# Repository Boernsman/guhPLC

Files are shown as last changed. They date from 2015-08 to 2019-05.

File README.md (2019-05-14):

# nymea PLC
The purpose was to design a smart home server that runns guhIO and is especially fittet to the needs of single-family house builders. It is the central switching unit that can be mounted into the electrical cabinet.

Please note: guhPLC is the abbreviation for 'guh' programmable logic controller. The smart home server has no powerline interface yet.

The layout is not yet tested - no warranty for functionality

	Copyright guh GmbH 2015-2019.

	This documentation describes Open Hardware and is licensed under the CERN OHL v. 1.2.

	You may redistribute and modify this documentation under the terms of the CERN OHL v.1.2. (http://ohwr.org/cernohl).
	
	This documentation is distributed WITHOUT ANY EXPRESS OR IMPLIED WARRANTY, INCLUDING OF MERCHANTABILITY,
	SATISFACTORY QUALITY AND FITNESS FOR A PARTICULAR PURPOSE. Please see the CERN OHL v.1.2 for applicable conditions

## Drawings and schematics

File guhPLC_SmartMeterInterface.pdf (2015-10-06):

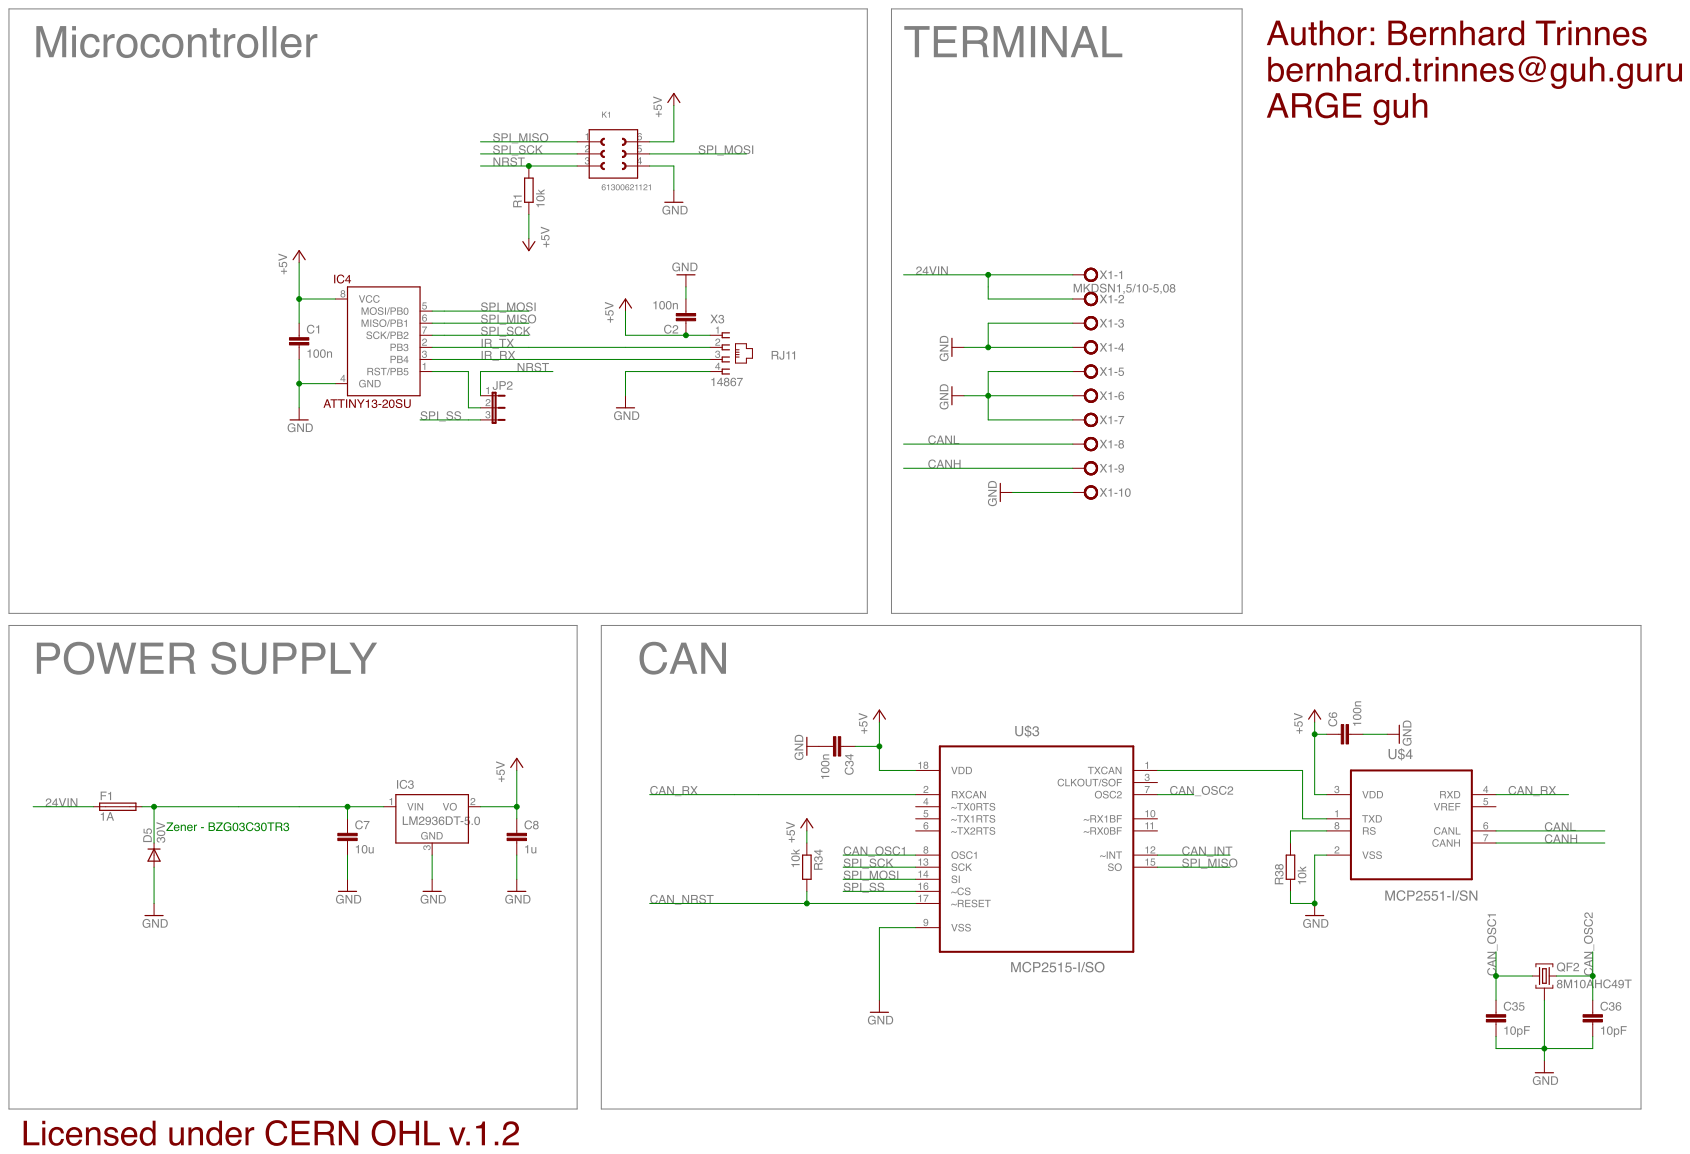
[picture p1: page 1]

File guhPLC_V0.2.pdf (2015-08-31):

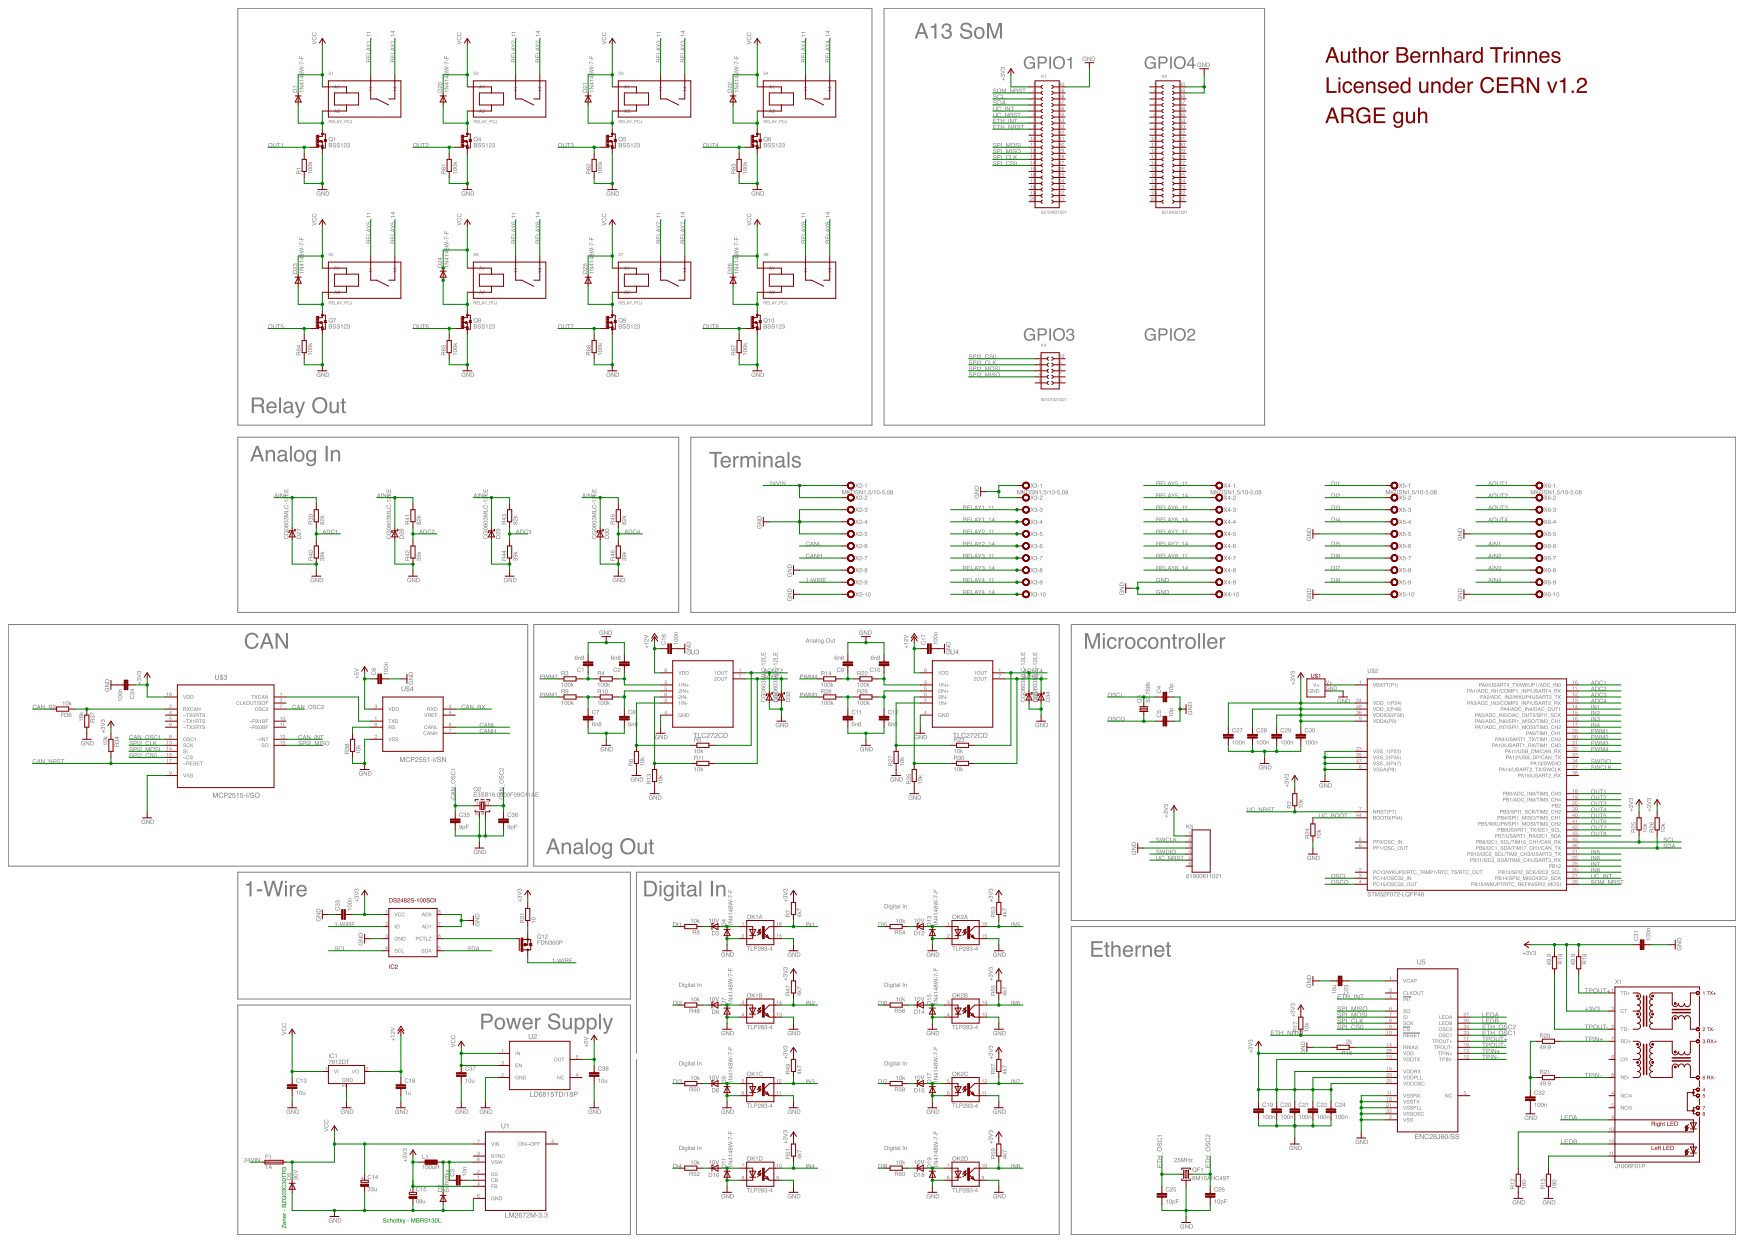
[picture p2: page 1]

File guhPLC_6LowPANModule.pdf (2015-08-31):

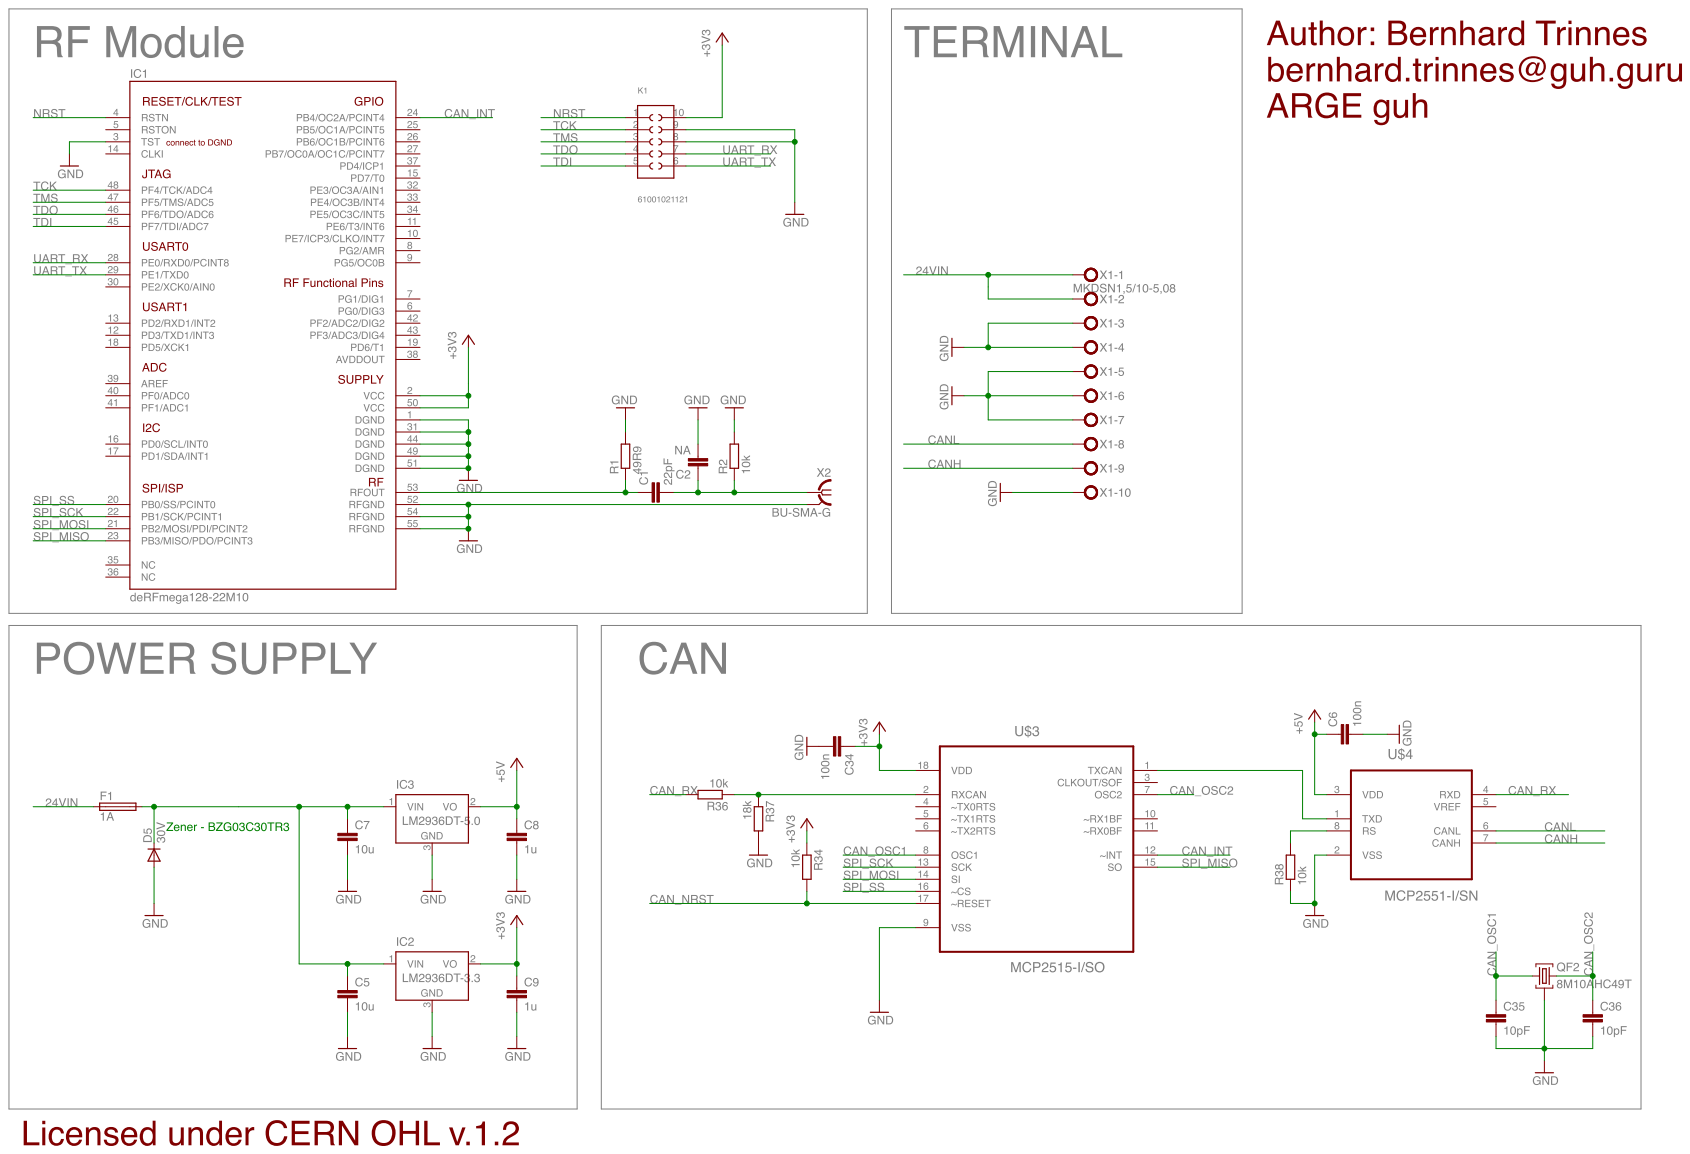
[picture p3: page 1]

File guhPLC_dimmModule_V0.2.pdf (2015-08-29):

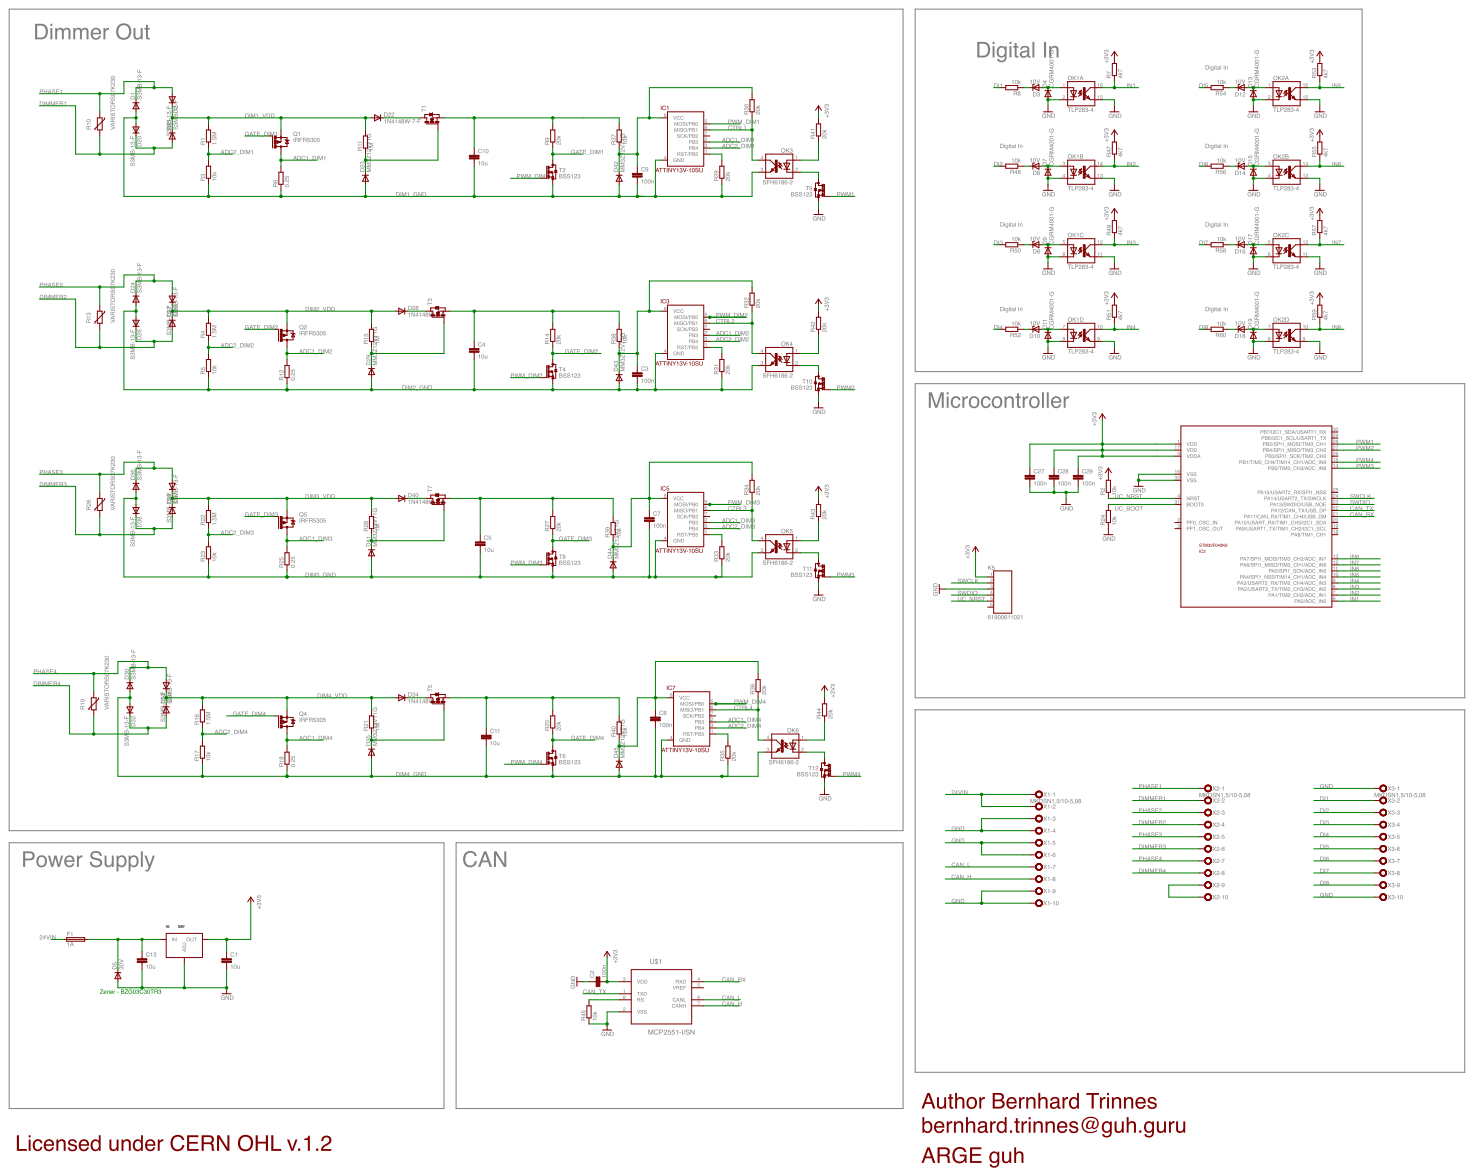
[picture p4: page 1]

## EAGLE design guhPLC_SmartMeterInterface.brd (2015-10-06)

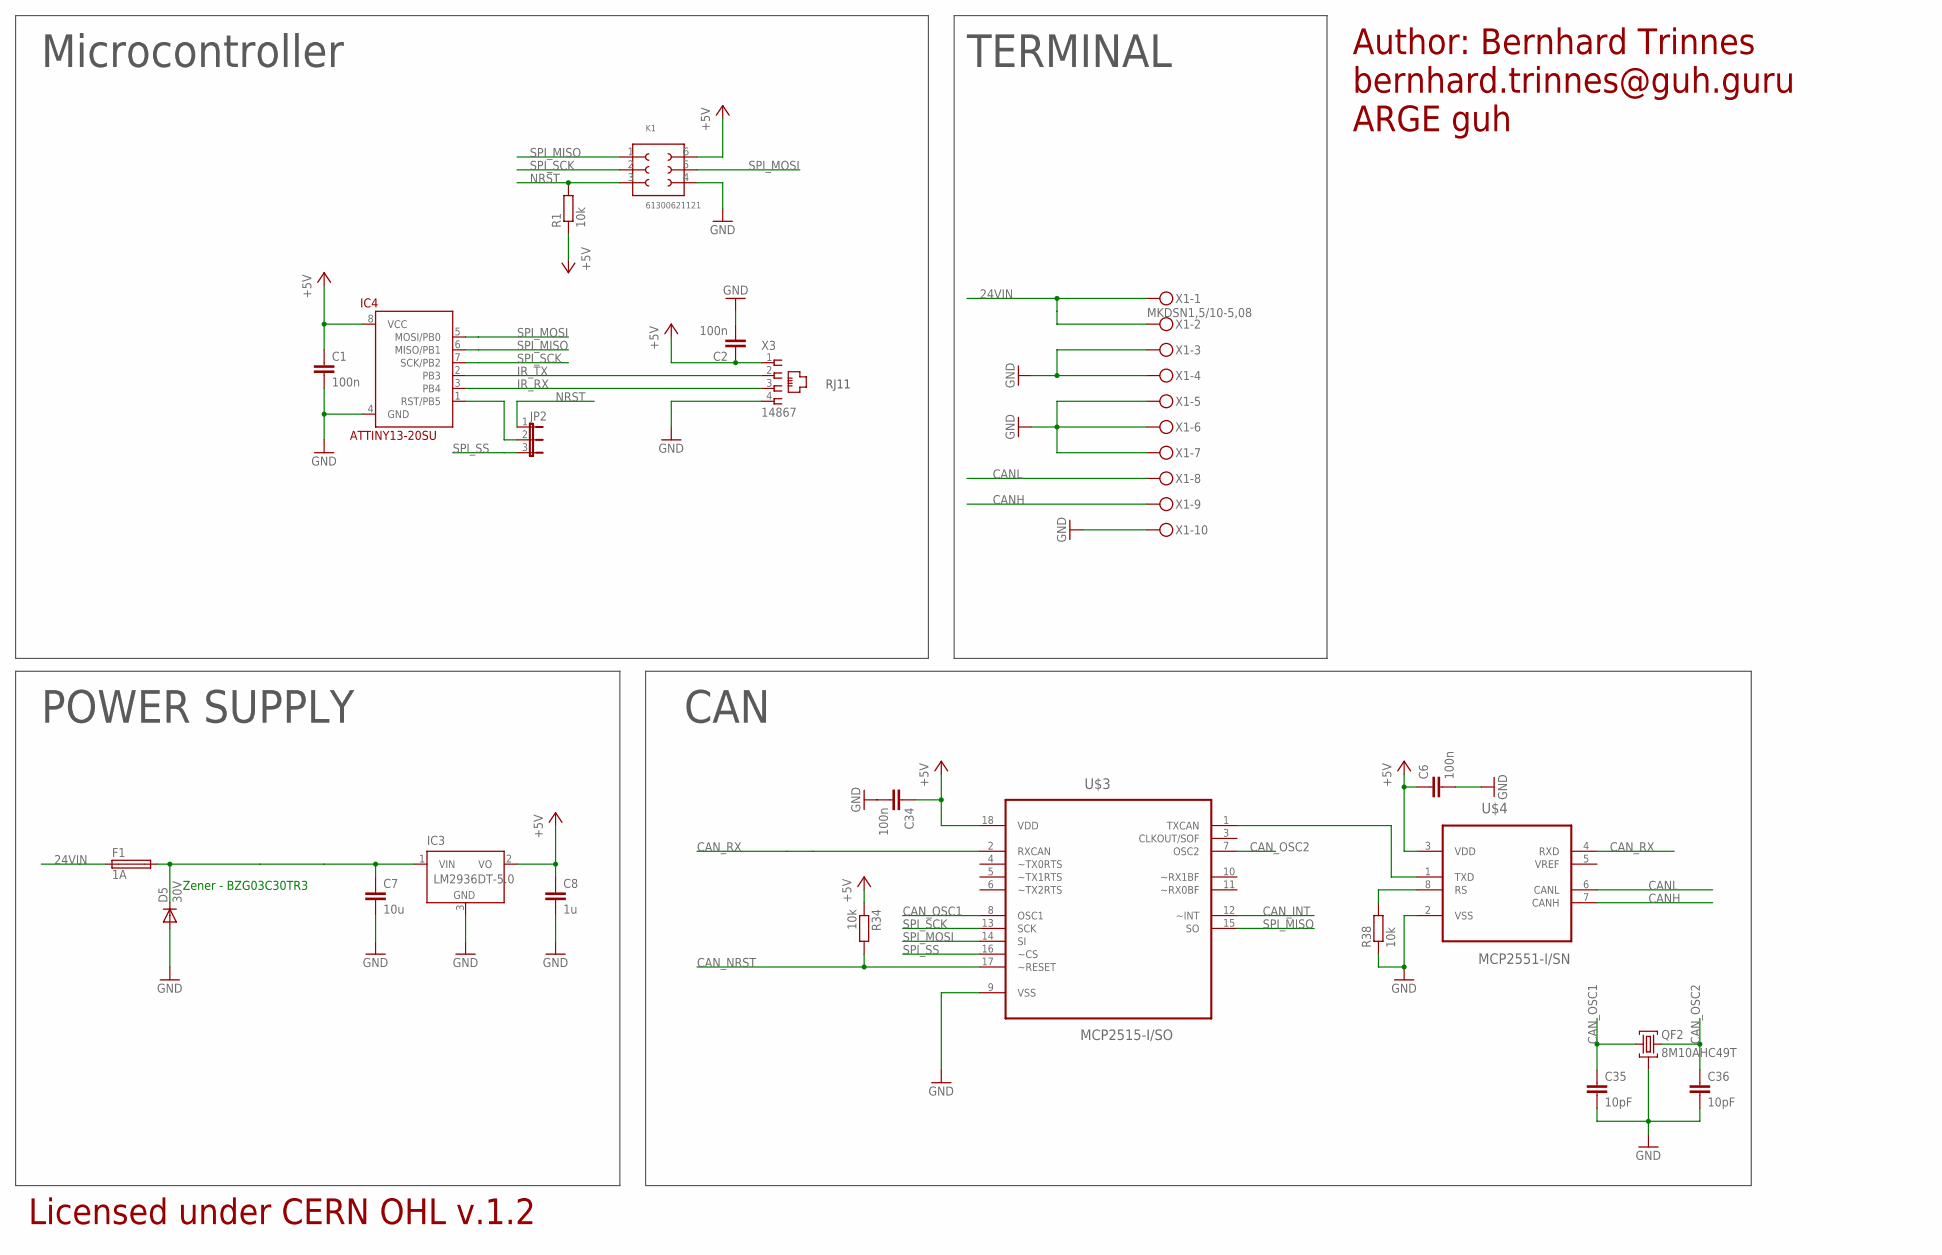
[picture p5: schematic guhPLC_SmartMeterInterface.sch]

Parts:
C1, C2, C6, C34: 100n; C0603
C7: 10u; C1206
C8: 1u; C0603
C35, C36: 10pF; C0603
D5: 30V; DO214AC
F1: 1A; LITTLEFUSE
IC3: LM2936DT-5.0; TO252
IC4: ATTINY13-20SU; SOIC8
JP2: JP2E; JP2
K1: 61300621121
QF2: 8M10AHC49T; HC49U
R1, R34, R38: 10k; R0603
U$3: MCP2515-I/SO; SOIC127P1034X264-18N
U$4: MCP2551-I/SN; SOIC127P600X175-8N
X1: MKDSN1,5/10-5,08
X3: 14867

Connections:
24VIN: F1.1, X1.1, X1.2
+5V: C1.1, C2.1, C6.1, C8.1, C34.1, IC3.2 (VO), IC4.8 (VCC), K1.6, R1.1, R34.1, U$3.18 (VDD), U$4.3 (VDD), X3.1
CANH: U$4.7 (CANH), X1.9
CANL: U$4.6 (CANL), X1.8
CAN_INT: U$3.12 (~INT)
CAN_NRST: R34.2, U$3.17 (~RESET)
CAN_OSC1: C35.1, QF2.1, U$3.8 (OSC1)
CAN_OSC2: C36.1, QF2.3, U$3.7 (OSC2)
CAN_RX: U$3.2 (RXCAN), U$4.4 (RXD)
GND: C1.2, C2.2, C6.2, C7.2, C8.2, C34.2, C35.2, C36.2, D5.A, IC3.3 (GND), IC4.4 (GND), K1.4, QF2.2, R38.1, U$3.9 (VSS), U$4.2 (VSS), X1.3, X1.4, X1.5, X1.6, X1.7, X1.10, X3.4
IR_RX: IC4.3 (PB4), X3.3
IR_TX: IC4.2 (PB3), X3.2
unnamed: IC4.1 (RST/PB5), JP2.2
unnamed: U$3.1 (TXCAN), U$4.1 (TXD)
unnamed: R38.2, U$4.8 (RS)
NRST: JP2.1, K1.3, R1.2
SPI_MISO: IC4.6 (MISO/PB1), K1.1, U$3.15 (SO)
SPI_MOSI: IC4.5 (MOSI/PB0), K1.5, U$3.14 (SI)
SPI_SCK: IC4.7 (SCK/PB2), K1.2, U$3.13 (SCK)
SPI_SS: JP2.3, U$3.16 (~CS)
VCC: C7.1, D5.C, F1.2, IC3.1 (VIN)

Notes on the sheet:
CAN
POWER SUPPLY
Microcontroller
TERMINAL
Author: Bernhard Trinnes
bernhard.trinnes@guh.guru
ARGE guh
Licensed under CERN OHL v.1.2
Zener - BZG03C30TR3
RJ11

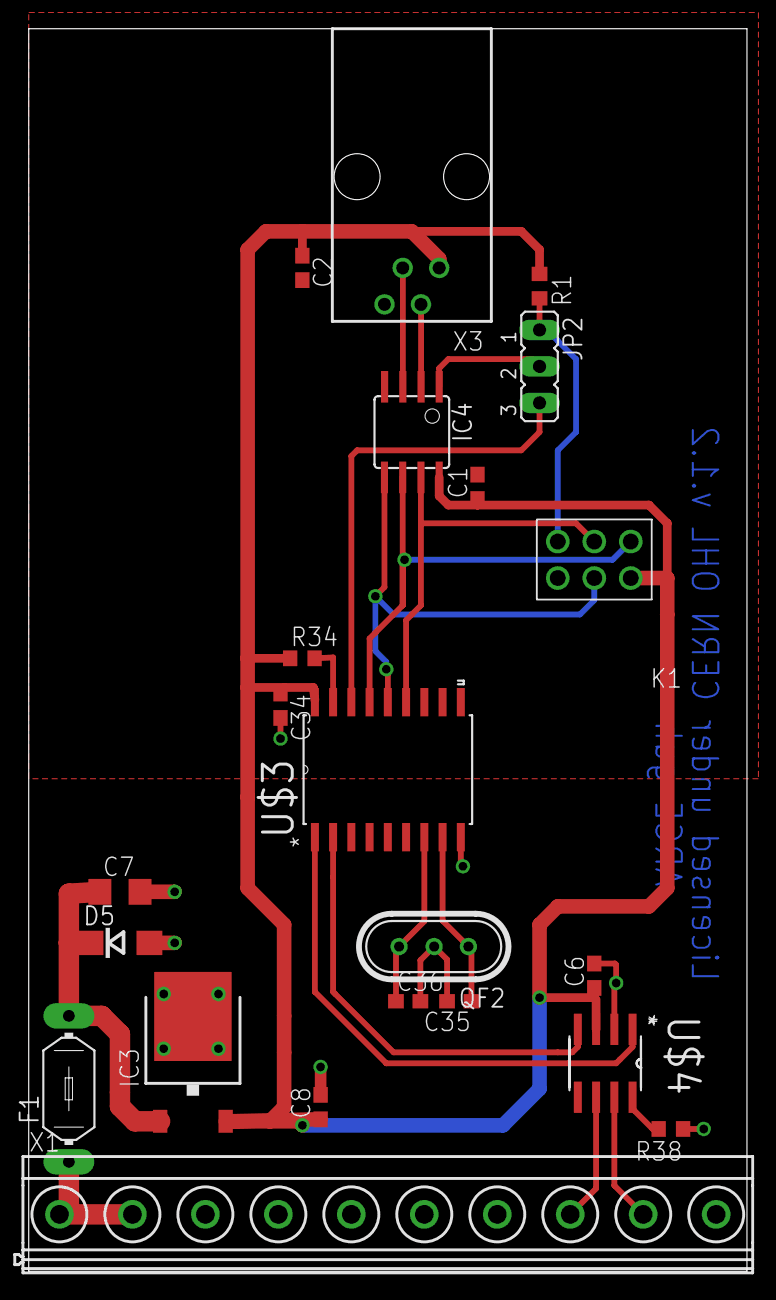
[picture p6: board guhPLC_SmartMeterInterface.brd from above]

Board: 2 copper layers, 50.0 x 86.5 mm, 22 parts (0 on the bottom side), 20 nets.

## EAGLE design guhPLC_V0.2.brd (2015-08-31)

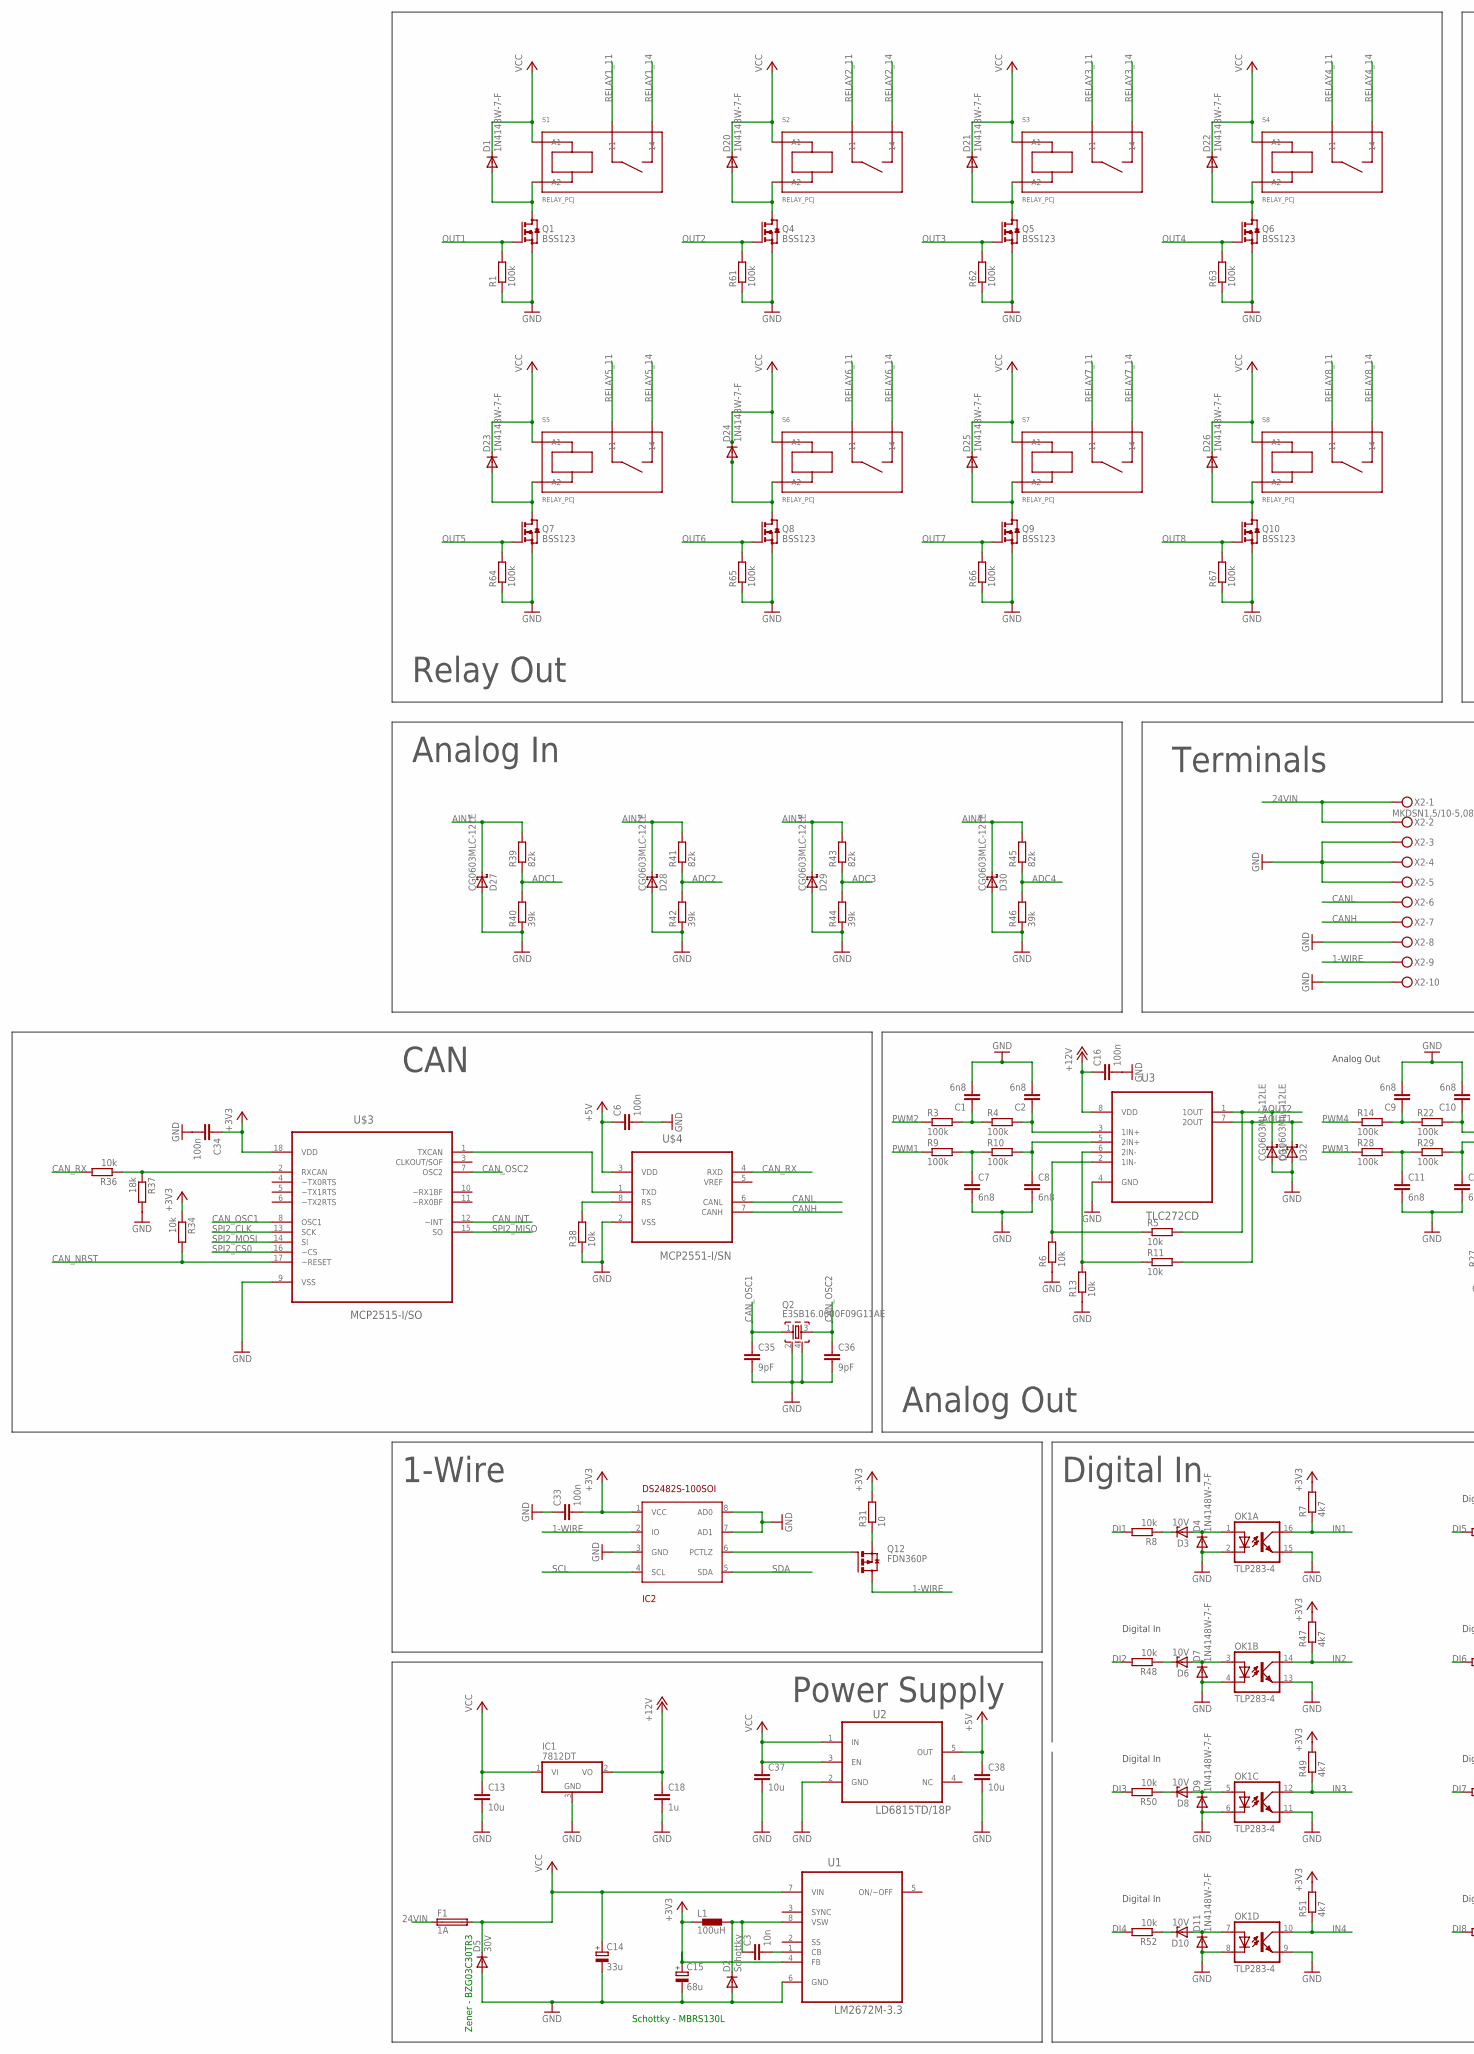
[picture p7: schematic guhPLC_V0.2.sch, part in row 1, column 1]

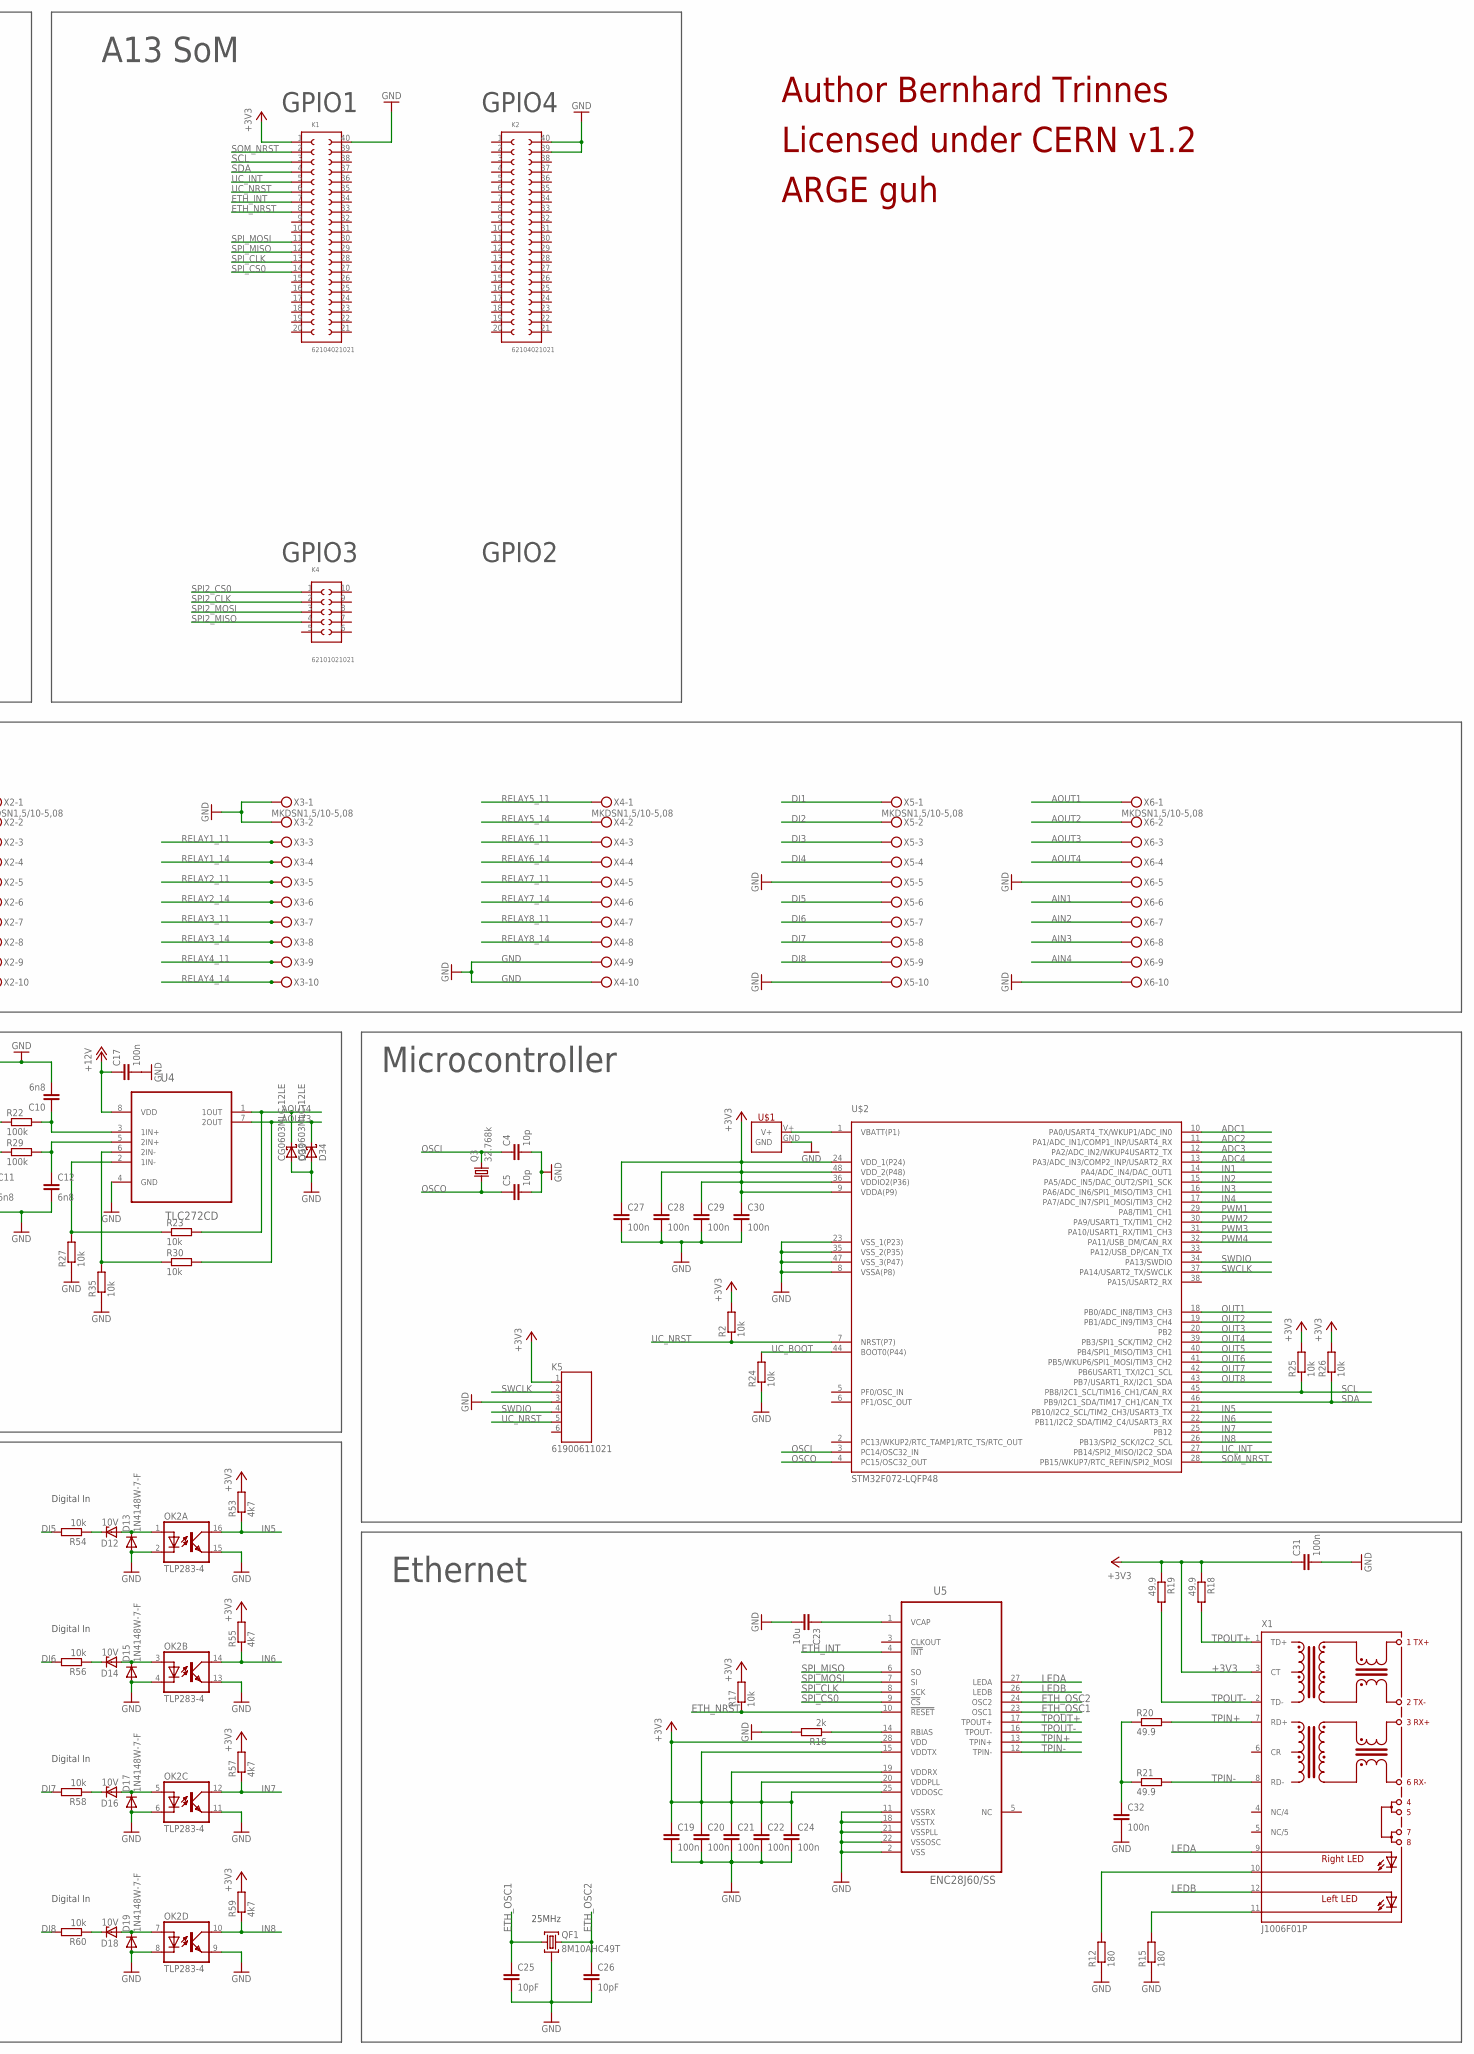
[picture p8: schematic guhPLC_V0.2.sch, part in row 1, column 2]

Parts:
C1, C2, C7, C8, C9, C10, C11, C12: 6n8; C0603
C3: 10n; C0603
C4, C5: 10p; C0603
C6, C16, C17, C19, C20, C21, C22, C24, C27, C28, C29, C30, C31, C33, C34: 100n; C0603
C13, C37, C38: 10u; C1206
C14: 33u; CT7343
C15: 68u; CT6032
C18: 1u; C1206
C23: 10u; C0603
C25, C26: 10pF; C0603
C32: 100n; C0402
C35, C36: 9pF; C0603
D1, D4, D7, D9, D11, D13, D15, D17, D19, D20, D21, D22, D23, D24, D25, D26: 1N4148W-7-F; SOD123
D2: Schottky; DO214AA
D3, D6, D8, D10, D12, D14, D16, D18: 10V; SOD80C
D5: 30V; DO214AC
D27, D28, D29, D30, D31, D32, D33, D34: CG0603MLC-12LE; R0603
F1: 1A; LITTLEFUSE
IC1: 7812DT; TO252
IC2: DS2482S-100SOI; SOIC127P600X175-8N
K1, K2: 62104021021
K4: 62101021021
K5: 61900611021
L1: 100uH; DR1030
OK1, OK2: TLP283-4; MINI-FLAT-16
Q1, Q4, Q5, Q6, Q7, Q8, Q9, Q10: BSS123; SOT23
Q2: E3SB16.0000F09G11AE; E3SBXXXXXXXF09G11AE
Q3: 32.768k; TC26H
Q12: FDN360P; SUPER-SOT3
QF1: 8M10AHC49T; HC49U
R1, R3, R4, R9, R10, R14, R22, R28, R29, R61, R62, R63, R64, R65, R66, R67: 100k; R0603
R2, R17, R24, R25, R26, R34, R36, R38: 10k; R0603
R5, R6, R8, R11, R13, R23, R27, R30, R35, R48, R50, R52, R54, R56, R58, R60: 10k; R0805
R7, R47, R49, R51, R53, R55, R57, R59: 4k7; R0603
R12, R15: 180; R0603
R16: 2k; R0603
R18, R19, R20, R21: 49.9; R0603
R31: 10; R0805
R37: 18k; R0603
R39, R41, R43, R45: 82k; R0805
R40, R42, R44, R46: 39k; R0805
S1, S2, S3, S4, S5, S6, S7, S8: RELAY_PCJ
U1: LM2672M-3.3; SOIC127P600X175-8N
U2: LD6815TD/18P; SOT95P275X110-5N
U3, U4: TLC272CD; SOIC127P600X175-8N
U5: ENC28J60/SS; SOP65P780X200-28N
U$1: MULTICOMP-CH7410-2032LF
U$2: STM32F072-LQFP48; LQFP48
U$3: MCP2515-I/SO; SOIC127P1034X264-18N
U$4: MCP2551-I/SN; SOIC127P600X175-8N
X1: J1006F01P; J1
X2, X3, X4, X5, X6: MKDSN1,5/10-5,08

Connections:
1-WIRE: IC2.2 (IO), Q12.3 (D), X2.9
24VIN: F1.1, X2.1, X2.2
+3V3: C15.+, C19.1, C20.1, C21.1, C22.1, C24.1, C27.1, C28.1, C29.1, C30.1, C31.1, C33.2, C34.1, IC2.1 (VCC), K1.1, K5.1, L1.1, R2.2, R7.2, R17.2, R18.1, R19.1, R25.2, R26.2, R31.2, R34.1, R47.2, R49.2, R51.2, R53.2, R55.2, R57.2, R59.2, U1.4 (FB), U5.15 (VDDTX), U5.19 (VDDRX), U5.20 (VDDPLL), U5.25 (VDDOSC), U5.28 (VDD), U$2.9 (VDDA(P9)), U$2.24 (VDD_1(P24)), U$2.36 (VDDIO2(P36)), U$2.48 (VDD_2(P48)), U$3.18 (VDD), X1.3 (CT)
+5V: C6.1, C38.1, U2.5 (OUT), U$4.3 (VDD)
+12V: C16.1, C17.1, C18.1, IC1.2 (VO), U3.8 (VDD), U4.8 (VDD)
ADC1: R39.1, R40.2, U$2.10 (PA0/USART4_TX/WKUP1/ADC_IN0)
ADC2: R41.1, R42.2, U$2.11 (PA1/ADC_IN1/COMP1_INP/USART4_RX)
ADC3: R43.1, R44.2, U$2.12 (PA2/ADC_IN2/WKUP4USART2_TX)
ADC4: R45.1, R46.2, U$2.13 (PA3/ADC_IN3/COMP2_INP/USART2_RX)
AIN1: D27.2 (C), R39.2, X6.6
AIN2: D28.2 (C), R41.2, X6.7
AIN3: D29.2 (C), R43.2, X6.8
AIN4: D30.2 (C), R45.2, X6.9
AOUT1: D32.2 (C), R11.2, U3.7 (2OUT), X6.1
AOUT2: D31.2 (C), R5.2, U3.1 (1OUT), X6.2
AOUT3: D34.2 (C), R30.2, U4.7 (2OUT), X6.3
AOUT4: D33.2 (C), R23.2, U4.1 (1OUT), X6.4
CANH: U$4.7 (CANH), X2.7
CANL: U$4.6 (CANL), X2.6
CAN_INT: U$3.12 (~INT)
CAN_NRST: R34.2, U$3.17 (~RESET)
CAN_OSC1: C35.1, Q2.1, U$3.8 (OSC1)
CAN_OSC2: C36.1, Q2.3, U$3.7 (OSC2)
CAN_RX: R36.2, U$4.4 (RXD)
DI1: R8.2, X5.1
DI2: R48.2, X5.2
DI3: R50.2, X5.3
DI4: R52.2, X5.4
DI5: R54.2, X5.6
DI6: R56.2, X5.7
DI7: R58.2, X5.8
DI8: R60.2, X5.9
ETH_INT: K1.7, U5.4 (!INT)
ETH_NRST: K1.8, R17.1, U5.10 (!RESET)
ETH_OSC1: C25.1, QF1.1, U5.23 (OSC1)
ETH_OSC2: C26.1, QF1.3, U5.24 (OSC2)
GND: C1.2, C2.2, C4.2, C5.2, C6.2, C7.2, C8.2, C9.2, C10.2, C11.2, C12.2, C13.2, C14.-, C15.-, C16.2, C17.2, C18.2, C19.2, C20.2, C21.2, C22.2, C23.2, C24.2, C25.2, C26.2, C27.2, C28.2, C29.2, C30.2, C31.2, C32.2, C33.1, C34.2, C35.2, C36.2, C37.2, C38.2, D2.A, D4.A, D5.A, D7.A, D9.A, D11.A, D13.A, D15.A, D17.A, D19.A, D27.1 (A), D28.1 (A), D29.1 (A), D30.1 (A), D31.1 (A), D32.1 (A), D33.1 (A), D34.1 (A), IC1.3 (GND), IC2.3 (GND), IC2.7 (AD1), IC2.8 (AD0), K1.40, K2.39, K2.40, K5.3, OK1.2 (C), OK1.4 (C), OK1.6 (C), OK1.8 (C), OK1.9 (EMIT), OK1.11 (EMIT), OK1.13 (EMIT), OK1.15 (EMIT), OK2.2 (C), OK2.4 (C), OK2.6 (C), OK2.8 (C), OK2.9 (EMIT), OK2.11 (EMIT), OK2.13 (EMIT), OK2.15 (EMIT), Q1.2 (S), Q2.2, Q2.4, Q4.2 (S), Q5.2 (S), Q6.2 (S), Q7.2 (S), Q8.2 (S), Q9.2 (S), Q10.2 (S), QF1.2, R1.1, R6.1, R12.1, R13.1, R15.1, R16.2, R24.1, R27.1, R35.1, R37.2, R38.1, R40.1, R42.1, R44.1, R46.1, R61.1, R62.1, R63.1, R64.1, R65.1, R66.1, R67.1, U1.6 (GND), U2.2 (GND), U3.4 (GND), U4.4 (GND), U5.2 (VSS), U5.11 (VSSRX), U5.18 (VSSTX), U5.21 (VSSPLL), U5.22 (VSSOSC), U$1.GND, U$2.8 (VSSA(P8)), U$2.23 (VSS_1(P23)), U$2.35 (VSS_2(P35)), U$2.47 (VSS_3(P47)), U$3.9 (VSS), U$4.2 (VSS), X2.3, X2.4, X2.5, X2.8, X2.10, X3.1, X3.2, X4.9, X4.10, X5.5, X5.10, X6.5, X6.10
IN1: OK1.16 (COL), R7.1, U$2.14 (PA4/ADC_IN4/DAC_OUT1)
IN2: OK1.14 (COL), R47.1, U$2.15 (PA5/ADC_IN5/DAC_OUT2/SPI1_SCK)
IN3: OK1.12 (COL), R49.1, U$2.16 (PA6/ADC_IN6/SPI1_MISO/TIM3_CH1)
IN4: OK1.10 (COL), R51.1, U$2.17 (PA7/ADC_IN7/SPI1_MOSI/TIM3_CH2)
IN5: OK2.16 (COL), R53.1, U$2.21 (PB10/I2C2_SCL/TIM2_CH3/USART3_TX)
IN6: OK2.14 (COL), R55.1, U$2.22 (PB11/I2C2_SDA/TIM2_C4/USART3_RX)
IN7: OK2.12 (COL), R57.1, U$2.25 (PB12)
IN8: OK2.10 (COL), R59.1, U$2.26 (PB13/SPI2_SCK/I2C2_SCL)
LEDA: U5.27 (LEDA), X1.9 (A-R)
LEDB: U5.26 (LEDB), X1.12 (A-L)
unnamed: C3.2, U1.1 (CB)
unnamed: IC2.6 (PCTLZ), Q12.1 (G)
unnamed: U$1.V+, U$2.1 (VBATT(P1))
unnamed: D1.A, Q1.3 (D), S1.A2
unnamed: C7.1, R9.2, R10.1
unnamed: C1.1, R3.2, R4.1
unnamed: C2.1, R4.2, U3.3 (1IN+)
unnamed: D3.C, R8.1
unnamed: R5.1, R6.2, U3.2 (1IN-)
unnamed: D3.A, D4.C, OK1.1 (A)
unnamed: C8.1, R10.2, U3.5 (2IN+)
unnamed: D24.A, Q8.3 (D), S6.A2
unnamed: C9.1, R14.2, R22.1
unnamed: C10.1, R22.2, U4.3 (1IN+)
unnamed: R23.1, R27.2, U4.2 (1IN-)
unnamed: C3.1, D2.C, L1.2, U1.8 (VSW)
unnamed: C11.1, R28.2, R29.1
unnamed: C12.1, R29.2, U4.5 (2IN+)
unnamed: Q12.2 (S), R31.1
unnamed: U$3.1 (TXCAN), U$4.1 (TXD)
unnamed: D6.C, R48.1
unnamed: R36.1, R37.1, U$3.2 (RXCAN)
unnamed: D6.A, D7.C, OK1.3 (A)
unnamed: R38.2, U$4.8 (RS)
unnamed: C32.1, R20.1, R21.1
unnamed: C23.1, U5.1 (VCAP)
unnamed: R12.2, X1.10 (C-R)
unnamed: R15.2, X1.11 (C-L)
unnamed: R11.1, R13.2, U3.6 (2IN-)
unnamed: R30.1, R35.2, U4.6 (2IN-)
unnamed: D8.C, R50.1
unnamed: D8.A, D9.C, OK1.5 (A)
unnamed: D10.C, R52.1
unnamed: D10.A, D11.C, OK1.7 (A)
unnamed: D12.C, R54.1
unnamed: R16.1, U5.14 (RBIAS)
unnamed: D12.A, D13.C, OK2.1 (A)
unnamed: D14.C, R56.1
unnamed: D14.A, D15.C, OK2.3 (A)
unnamed: D16.C, R58.1
unnamed: D16.A, D17.C, OK2.5 (A)
unnamed: D18.C, R60.1
unnamed: D18.A, D19.C, OK2.7 (A)
unnamed: D20.A, Q4.3 (D), S2.A2
unnamed: D21.A, Q5.3 (D), S3.A2
unnamed: D22.A, Q6.3 (D), S4.A2
unnamed: D23.A, Q7.3 (D), S5.A2
unnamed: D25.A, Q9.3 (D), S7.A2
unnamed: D26.A, Q10.3 (D), S8.A2
OSCI: C4.1, Q3.2, U$2.3 (PC14/OSC32_IN)
OSCO: C5.1, Q3.1, U$2.4 (PC15/OSC32_OUT)
OUT1: Q1.1 (G), R1.2, U$2.18 (PB0/ADC_IN8/TIM3_CH3)
OUT2: Q4.1 (G), R61.2, U$2.19 (PB1/ADC_IN9/TIM3_CH4)
OUT3: Q5.1 (G), R62.2, U$2.20 (PB2)
OUT4: Q6.1 (G), R63.2, U$2.39 (PB3/SPI1_SCK/TIM2_CH2)
OUT5: Q7.1 (G), R64.2, U$2.40 (PB4/SPI1_MISO/TIM3_CH1)
OUT6: Q8.1 (G), R65.2, U$2.41 (PB5/WKUP6/SPI1_MOSI/TIM3_CH2)
OUT7: Q9.1 (G), R66.2, U$2.42 (PB6USART1_TX/I2C1_SCL)
OUT8: Q10.1 (G), R67.2, U$2.43 (PB7/USART1_RX/I2C1_SDA)
PWM1: R9.1, U$2.29 (PA8/TIM1_CH1)
PWM2: R3.1, U$2.30 (PA9/USART1_TX/TIM1_CH2)
PWM3: R28.1, U$2.31 (PA10/USART1_RX/TIM1_CH3)
PWM4: R14.1, U$2.32 (PA11/USB_DM/CAN_RX)
RELAY1_11: S1.11, X3.3
RELAY1_14: S1.14, X3.4
RELAY2_11: S2.11, X3.5
RELAY2_14: S2.14, X3.6
RELAY3_11: S3.11, X3.7
RELAY3_14: S3.14, X3.8
RELAY4_11: S4.11, X3.9
RELAY4_14: S4.14, X3.10
RELAY5_11: S5.11, X4.1
RELAY5_14: S5.14, X4.2
RELAY6_11: S6.11, X4.3
RELAY6_14: S6.14, X4.4
RELAY7_11: S7.11, X4.5
RELAY7_14: S7.14, X4.6
RELAY8_11: S8.11, X4.7
RELAY8_14: S8.14, X4.8
SCL: IC2.4 (SCL), K1.3, R25.1, U$2.45 (PB8/I2C1_SCL/TIM16_CH1/CAN_RX)
SDA: IC2.5 (SDA), K1.4, R26.1, U$2.46 (PB9/I2C1_SDA/TIM17_CH1/CAN_TX)
SOM_NRST: K1.2, U$2.28 (PB15/WKUP7/RTC_REFIN/SPI2_MOSI)
SPI2_CLK: K4.2, U$3.13 (SCK)
SPI2_CS0: K4.1, U$3.16 (~CS)
SPI2_MISO: K4.4, U$3.15 (SO)
SPI2_MOSI: K4.3, U$3.14 (SI)
SPI_CLK: K1.13, U5.8 (SCK)
SPI_CS0: K1.14, U5.9 (!CS)
SPI_MISO: K1.12, U5.6 (SO)
SPI_MOSI: K1.11, U5.7 (SI)
SWCLK: K5.2, U$2.37 (PA14/USART2_TX/SWCLK)
SWDIO: K5.4, U$2.34 (PA13/SWDIO)
TPIN+: R20.2, U5.13 (TPIN+), X1.7 (RD+)
TPIN-: R21.2, U5.12 (TPIN-), X1.8 (RD-)
TPOUT+: R18.2, U5.17 (TPOUT+), X1.1 (TD+)
TPOUT-: R19.2, U5.16 (TPOUT-), X1.2 (TD-)
UC_BOOT: R24.2, U$2.44 (BOOT0(P44))
UC_INT: K1.5, U$2.27 (PB14/SPI2_MISO/I2C2_SDA)
UC_NRST: K1.6, K5.5, R2.1, U$2.7 (NRST(P7))
VCC: C13.1, C14.+, C37.1, D1.C, D5.C, D20.C, D21.C, D22.C, D23.C, D24.C, D25.C, D26.C, F1.2, IC1.1 (VI), S1.A1, S2.A1, S3.A1, S4.A1, S5.A1, S6.A1, S7.A1, S8.A1, U1.7 (VIN), U2.1 (IN), U2.3 (EN)

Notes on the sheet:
A13 SoM
Analog Out
Analog In
Digital In
Power Supply
Microcontroller
CAN
Relay Out
GPIO1
GPIO2
GPIO3
GPIO4
Ethernet
25MHz
Terminals
Schottky - MBRS130L
Zener - BZG03C30TR3
Author Bernhard Trinnes
Licensed under CERN v1.2
ARGE guh
1-Wire

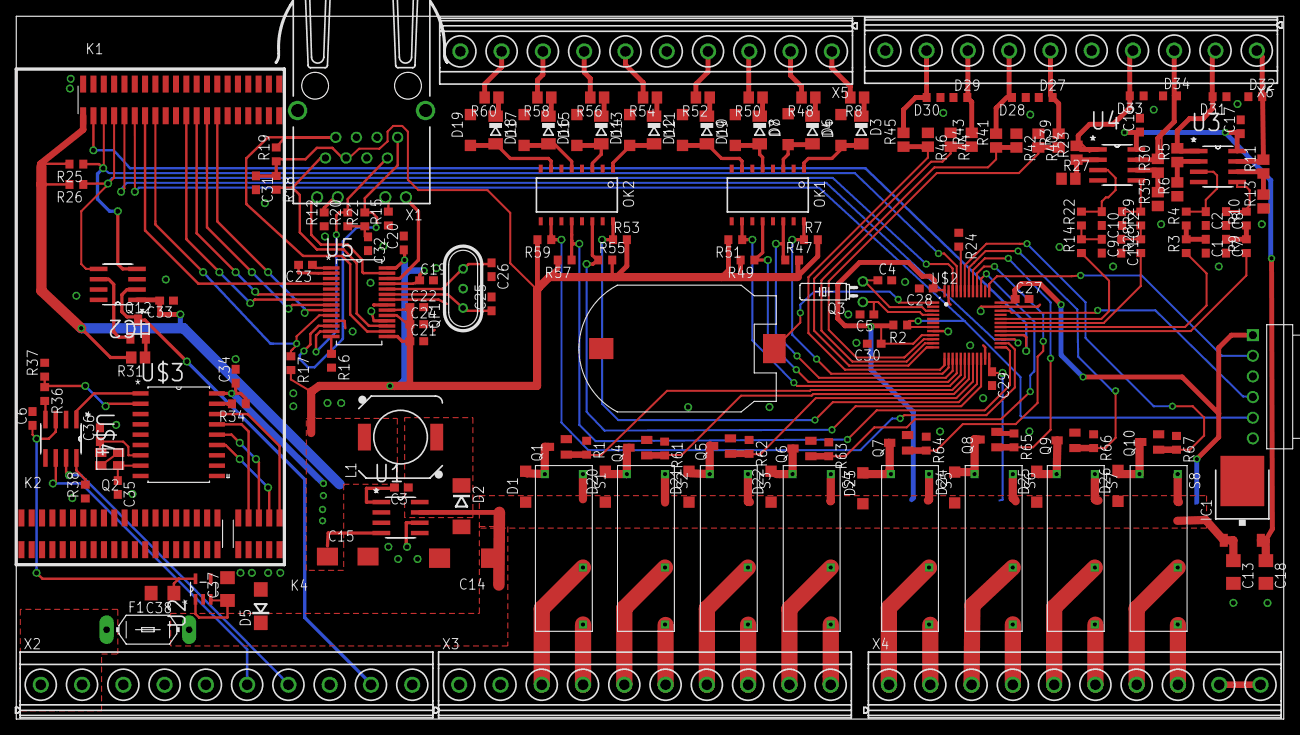
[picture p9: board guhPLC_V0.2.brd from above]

Board: 2 copper layers, 156.0 x 86.5 mm, 182 parts (0 on the bottom side), 146 nets.

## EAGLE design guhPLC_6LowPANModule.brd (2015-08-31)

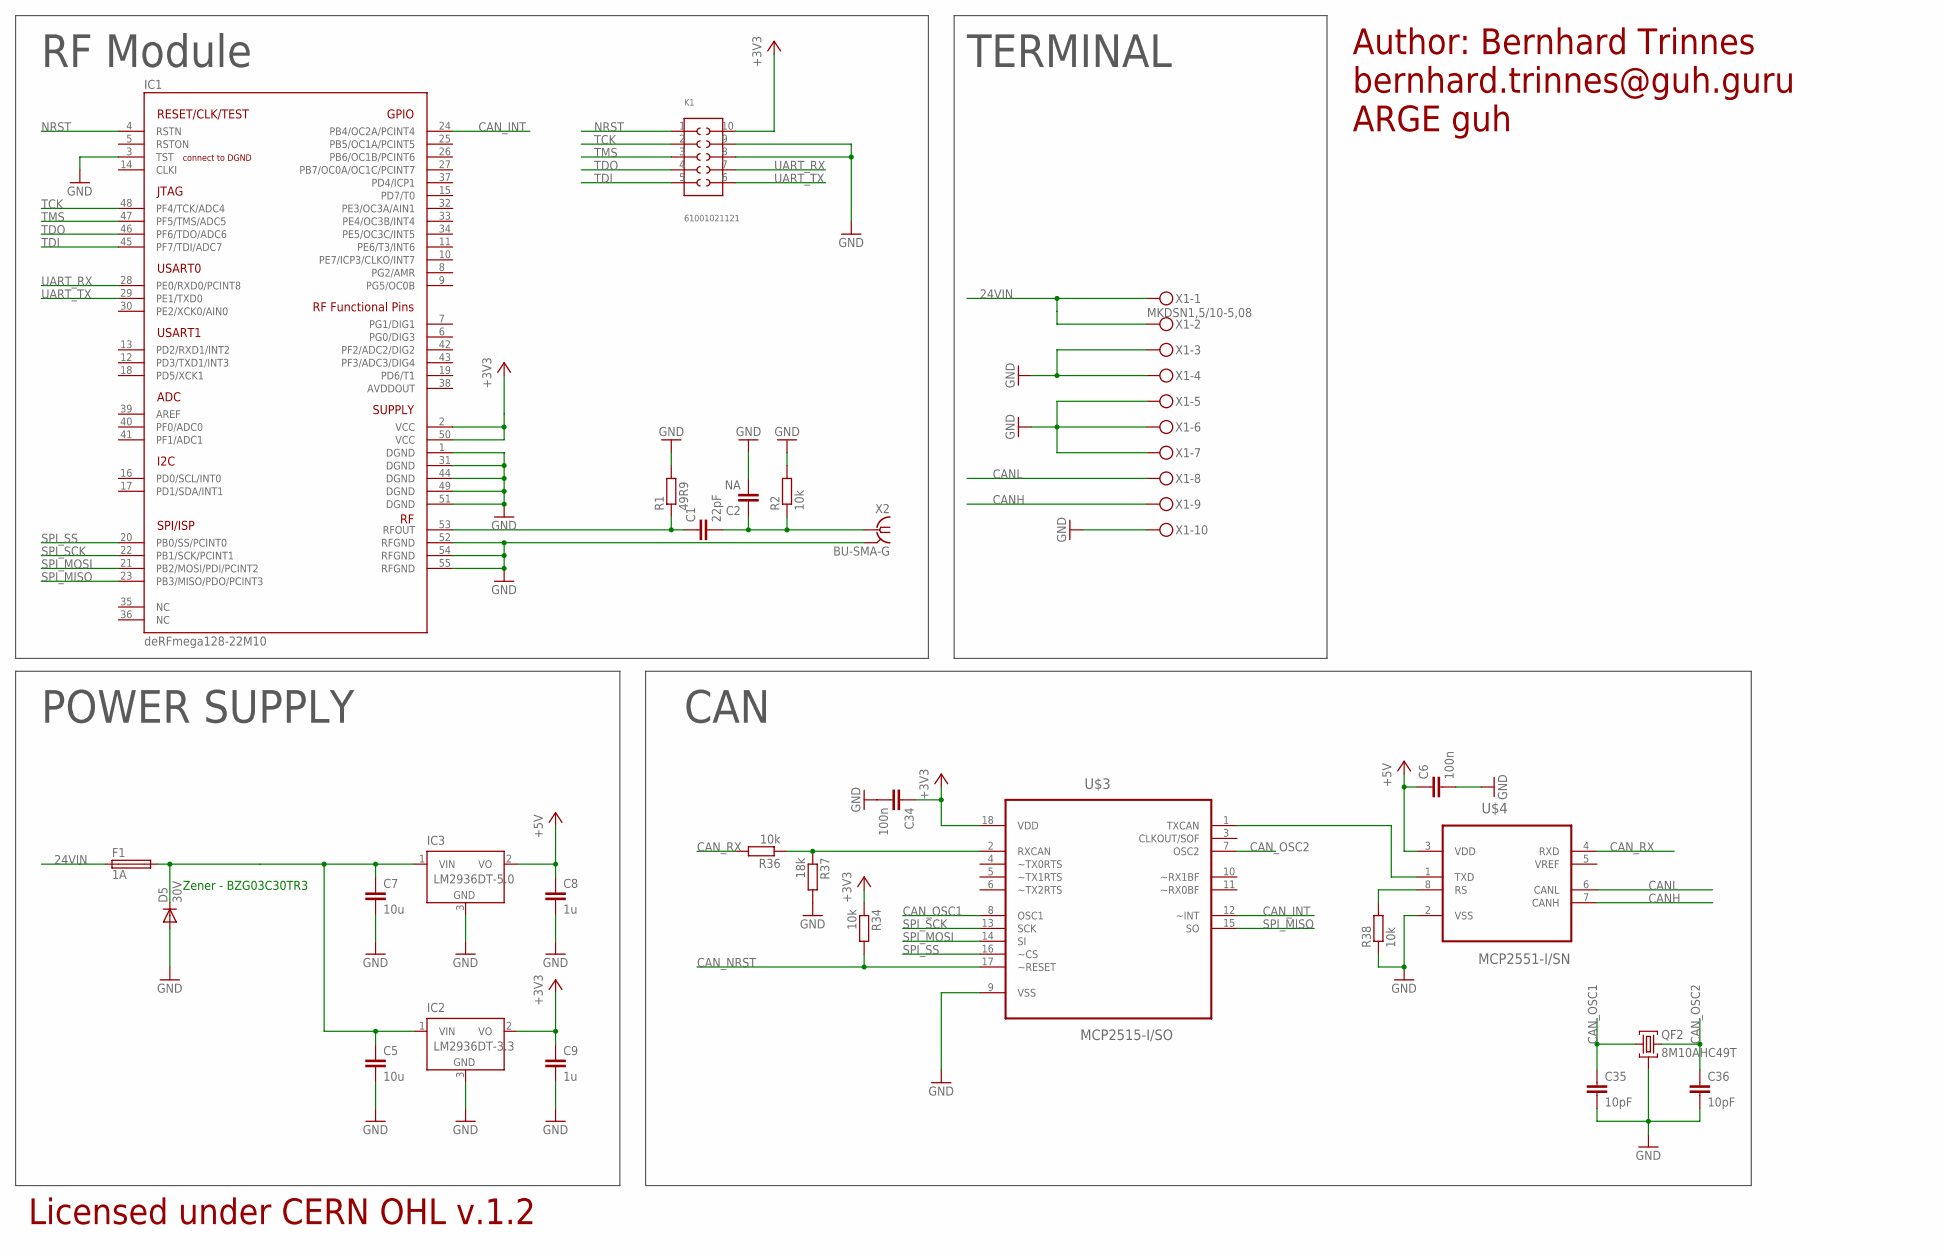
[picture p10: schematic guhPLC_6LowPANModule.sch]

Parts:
C1: 22pF; C0402
C2: NA; C0402
C5, C7: 10u; C1206
C6, C34: 100n; C0603
C8, C9: 1u; C0603
C35, C36: 10pF; C0603
D5: 30V; DO214AC
F1: 1A; LITTLEFUSE
IC1: DERFMEGA128-22M10; A-M10
IC2: LM2936DT-3.3; TO252
IC3: LM2936DT-5.0; TO252
K1: 61001021121
QF2: 8M10AHC49T; HC49U
R1: 49R9; R0402
R2: 10k; R0402
R34, R36, R38: 10k; R0603
R37: 18k; R0603
U$3: MCP2515-I/SO; SOIC127P1034X264-18N
U$4: MCP2551-I/SN; SOIC127P600X175-8N
X1: MKDSN1,5/10-5,08
X2: BU-SMA-G

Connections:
24VIN: F1.1, X1.1, X1.2
+3V3: C9.1, C34.1, IC1.2 (VCC), IC1.50 (VCC), IC2.2 (VO), K1.10, R34.1, U$3.18 (VDD)
+5V: C6.1, C8.1, IC3.2 (VO), U$4.3 (VDD)
CANH: U$4.7 (CANH), X1.9
CANL: U$4.6 (CANL), X1.8
CAN_INT: IC1.24 (PB4/OC2A/PCINT4), U$3.12 (~INT)
CAN_NRST: R34.2, U$3.17 (~RESET)
CAN_OSC1: C35.1, QF2.1, U$3.8 (OSC1)
CAN_OSC2: C36.1, QF2.3, U$3.7 (OSC2)
CAN_RX: R36.2, U$4.4 (RXD)
GND: C2.2, C5.2, C6.2, C7.2, C8.2, C9.2, C34.2, C35.2, C36.2, D5.A, IC1.1 (DGND), IC1.3 (TST), IC1.31 (DGND), IC1.44 (DGND), IC1.49 (DGND), IC1.51 (DGND), IC1.52 (RFGND), IC1.54 (RFGND), IC1.55 (RFGND), IC2.3 (GND), IC3.3 (GND), K1.8, K1.9, QF2.2, R1.2, R2.2, R37.2, R38.1, U$3.9 (VSS), U$4.2 (VSS), X1.3, X1.4, X1.5, X1.6, X1.7, X1.10, X2.2 (GND), X2.3 (GND), X2.4 (GND), X2.5 (GND)
unnamed: C1.2, C2.1, R2.1, X2.1
unnamed: U$3.1 (TXCAN), U$4.1 (TXD)
unnamed: R36.1, R37.1, U$3.2 (RXCAN)
unnamed: R38.2, U$4.8 (RS)
NRST: IC1.4 (RSTN), K1.1
RFOUT: C1.1, IC1.53 (RFOUT), R1.1
SPI_MISO: IC1.23 (PB3/MISO/PDO/PCINT3), U$3.15 (SO)
SPI_MOSI: IC1.21 (PB2/MOSI/PDI/PCINT2), U$3.14 (SI)
SPI_SCK: IC1.22 (PB1/SCK/PCINT1), U$3.13 (SCK)
SPI_SS: IC1.20 (PB0/SS/PCINT0), U$3.16 (~CS)
TCK: IC1.48 (PF4/TCK/ADC4), K1.2
TDI: IC1.45 (PF7/TDI/ADC7), K1.5
TDO: IC1.46 (PF6/TDO/ADC6), K1.4
TMS: IC1.47 (PF5/TMS/ADC5), K1.3
UART_RX: IC1.28 (PE0/RXD0/PCINT8), K1.7
UART_TX: IC1.29 (PE1/TXD0), K1.6
VCC: C5.1, C7.1, D5.C, F1.2, IC2.1 (VIN), IC3.1 (VIN)

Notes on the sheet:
CAN
POWER SUPPLY
RF Module
TERMINAL
Author: Bernhard Trinnes
bernhard.trinnes@guh.guru
ARGE guh
Licensed under CERN OHL v.1.2
Zener - BZG03C30TR3

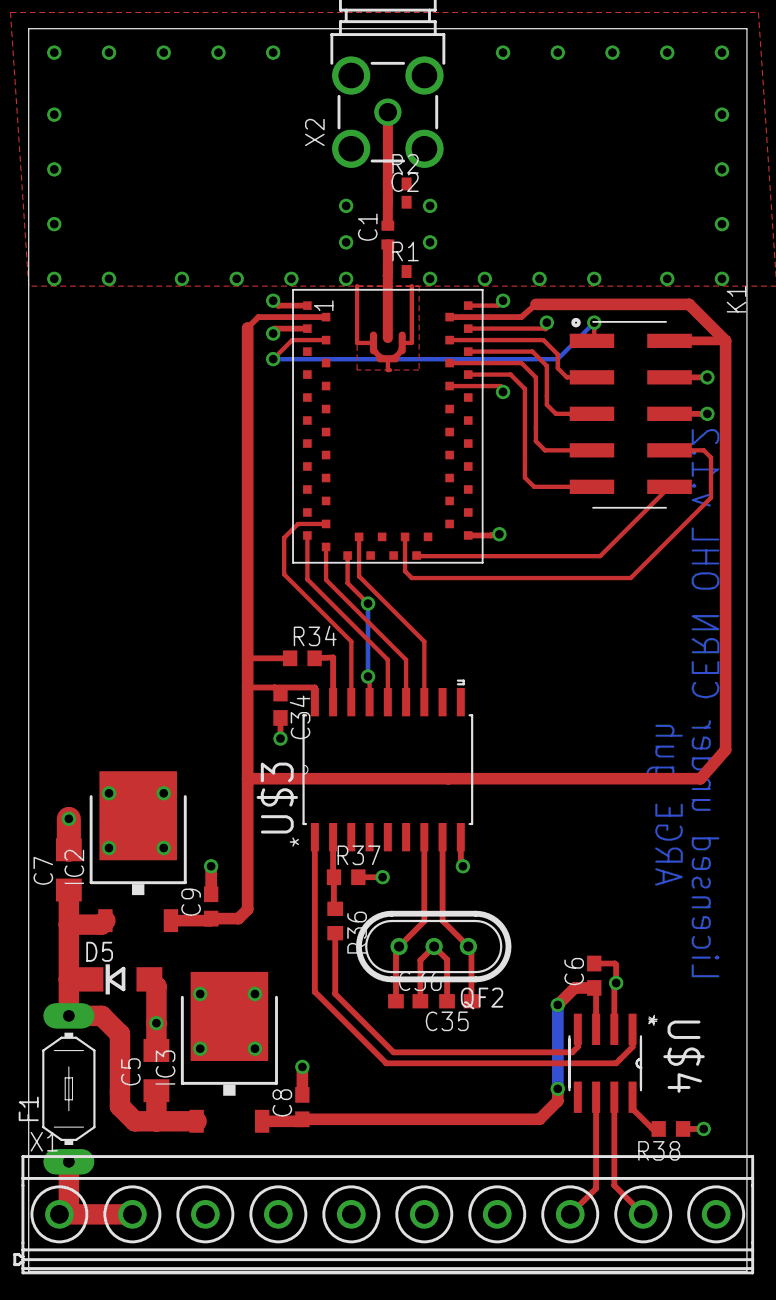
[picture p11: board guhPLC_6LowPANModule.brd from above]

Board: 2 copper layers, 50.0 x 86.5 mm, 27 parts (0 on the bottom side), 28 nets.

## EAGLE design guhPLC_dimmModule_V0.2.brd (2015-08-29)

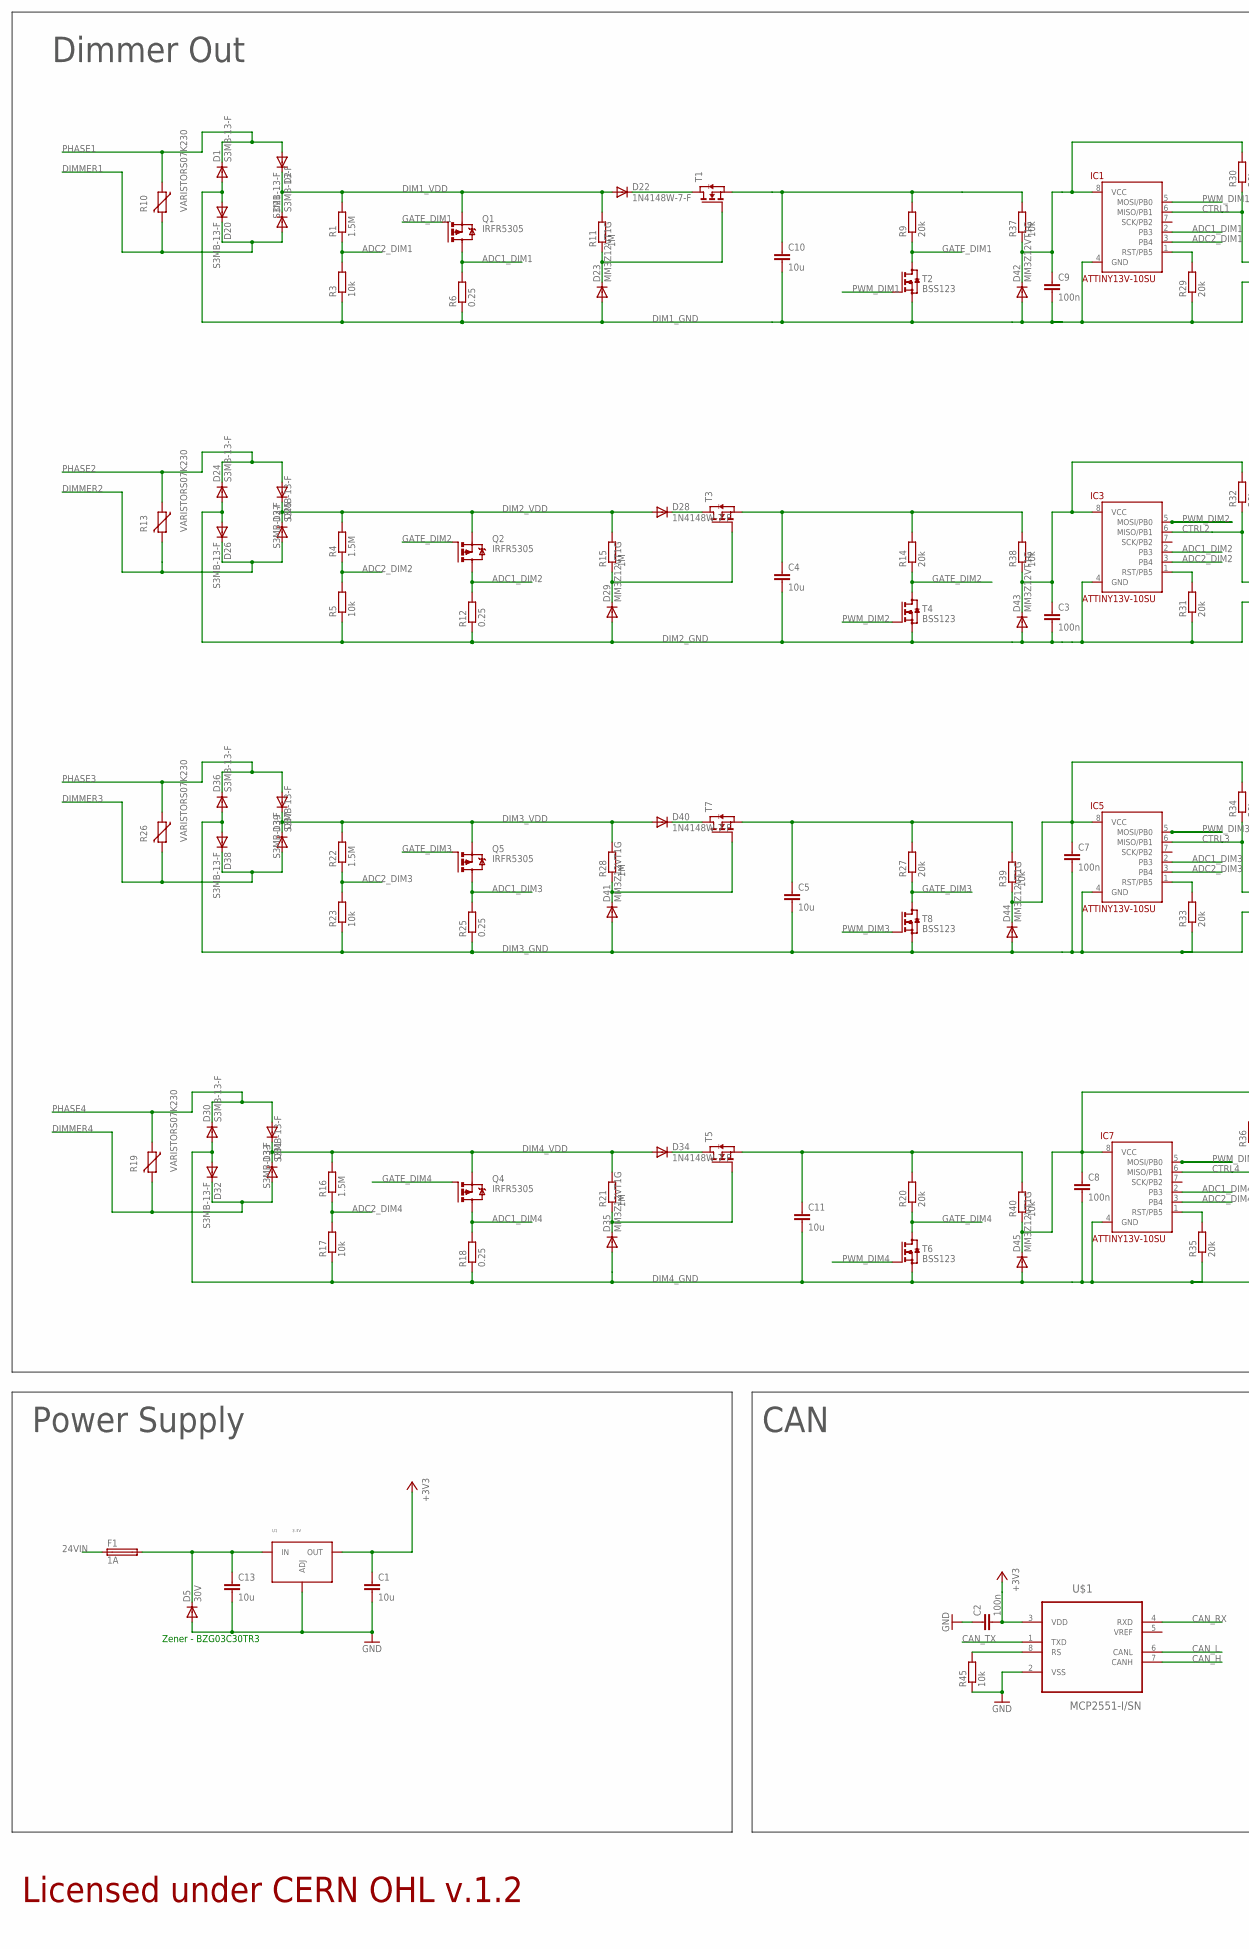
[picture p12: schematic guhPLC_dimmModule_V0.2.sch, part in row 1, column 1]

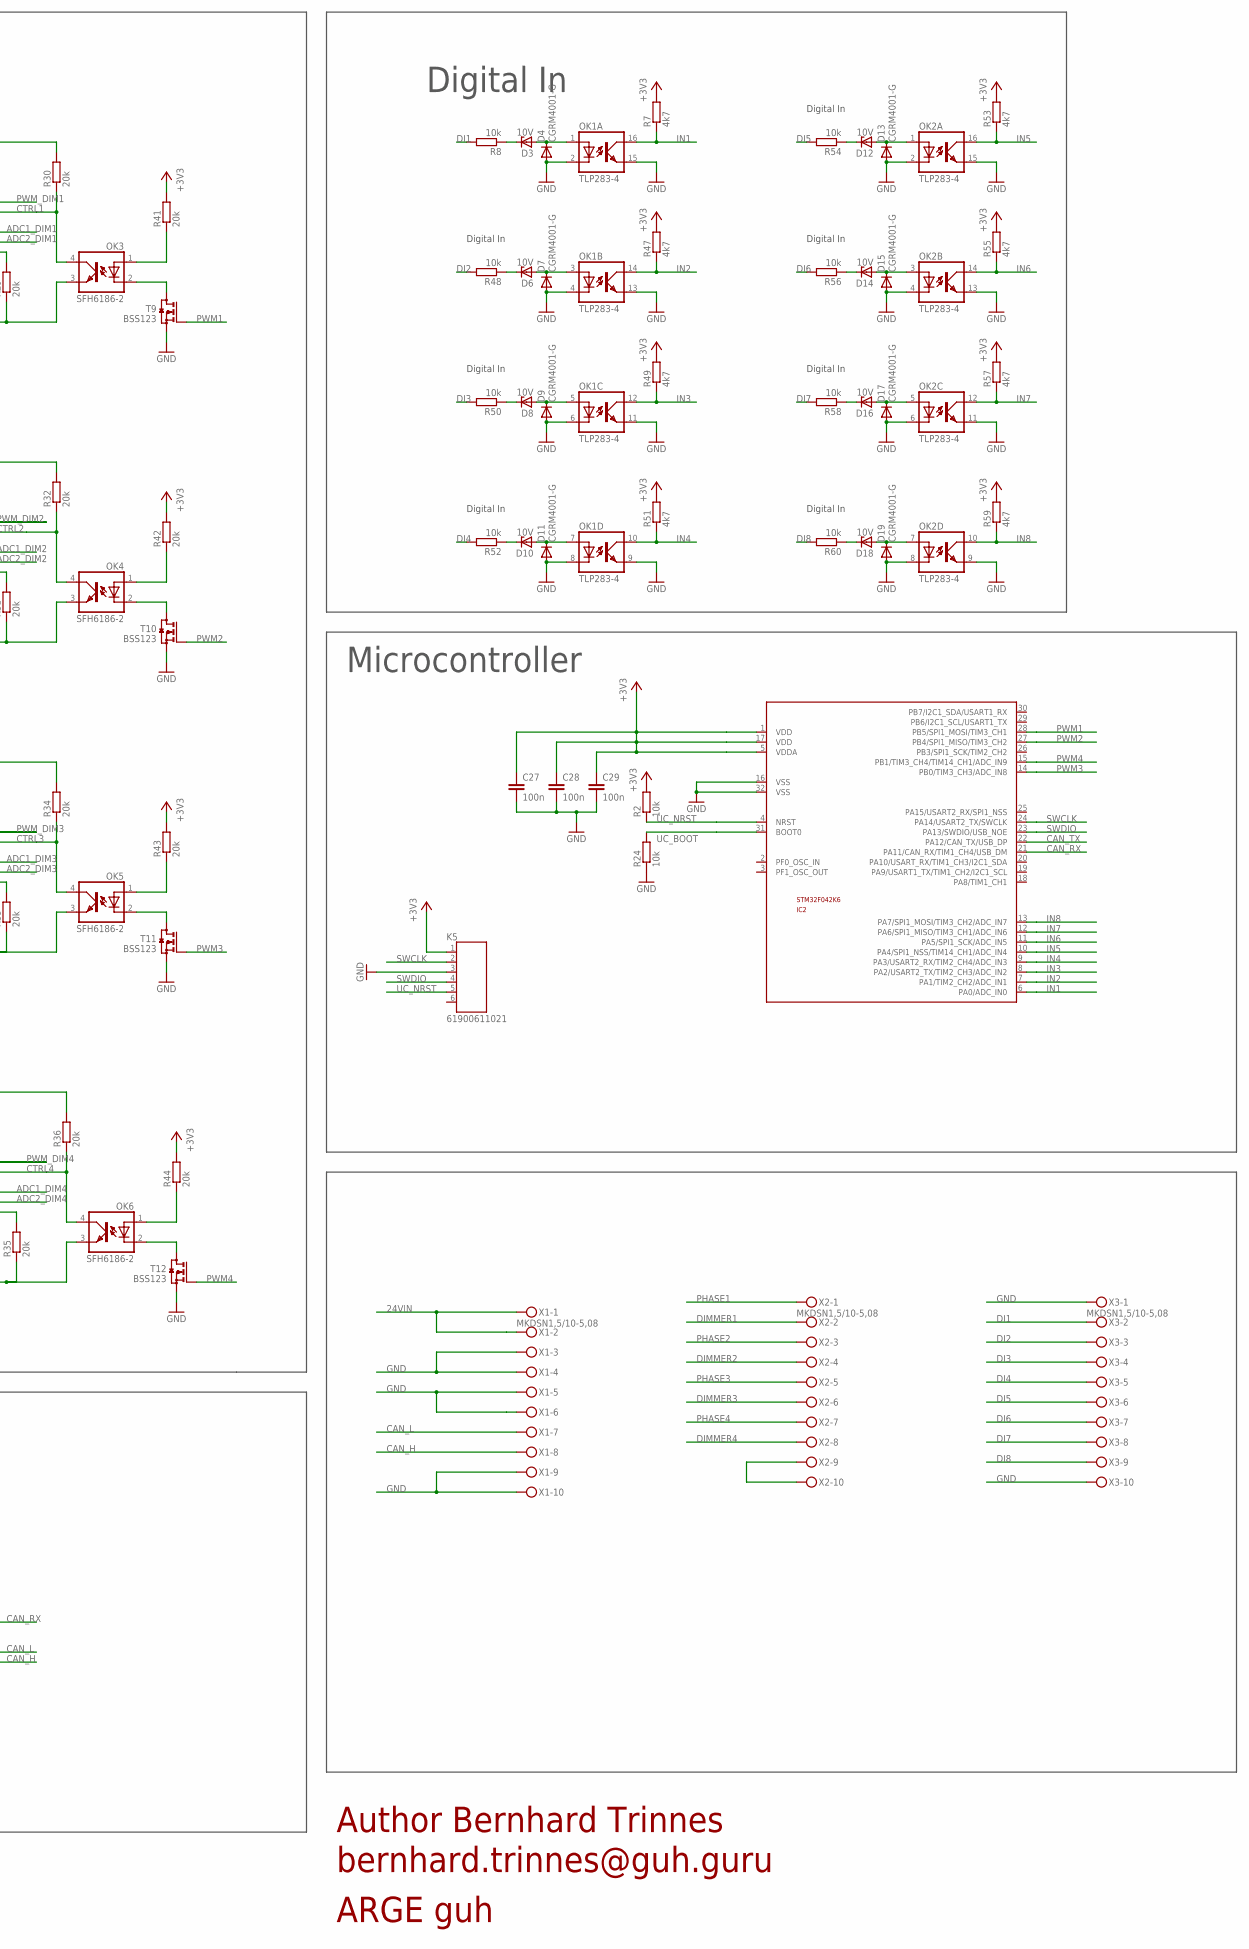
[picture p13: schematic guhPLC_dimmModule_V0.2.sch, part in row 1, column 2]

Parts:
C1, C4, C5, C10, C11, C13: 10u; C1206
C2, C3, C7, C8, C9, C27, C28, C29: 100n; C0603
D1, D2, D20, D21, D24, D25, D26, D27, D30, D31, D32, D33, D36, D37, D38, D39: S3MB-13-F; DO214AA
D3, D6, D8, D10, D12, D14, D16, D18: 10V; SOD80C
D4, D7, D9, D11, D13, D15, D17, D19: CGRM4001-G; SOD-123_MINI-SMA
D5: 30V; DO214AC
D22, D28, D34, D40: 1N4148W-7-F; SOD123
D23, D29, D35, D41, D42, D43, D44, D45: MM3Z12VT1G; SOD323-W
F1: 1A; LITTLEFUSE
IC1, IC3, IC5, IC7: ATTINY13V-10SU; SOIC8
IC2: STM32F042K6; LQFP32-7X7
K5: 61900611021
OK1, OK2: TLP283-4; MINI-FLAT-16
OK3, OK4, OK5, OK6: SFH6186-2; SMD4
Q1, Q2, Q4, Q5: IRFR5305; D-PAK_TO252AA
R1: 1.5M; R1206
R2, R24, R45: 10k; R0603
R3: 10k; R1206
R4, R16, R22: 1.5M; M1206
R5, R17, R23, R37, R38, R39, R40: 10k; M1206
R6: 0.25; R1206
R7, R47, R49, R51, R53, R55, R57, R59: 4k7; R0603
R8, R48, R50, R52, R54, R56, R58, R60: 10k; R0805
R9, R14, R20, R27: 20k; M1206
R10, R13, R19, R26: VARISTORS07K230; S07K230
R11: 1M; R1206
R12, R18, R25: 0.25; M1206
R15, R21, R28: 1M; M1206
R29, R30, R31, R32, R33, R34, R35, R36, R41, R42, R43, R44: 20k; R0603
T1, T3, T5, T7: NMOSSOT23; SOT-23
T2, T4, T6, T8, T9, T10, T11, T12: BSS123; SOT23
U1: 3.3V; TO-252-3L
U$1: MCP2551-I/SN; SOIC127P600X175-8N
X1, X2, X3: MKDSN1,5/10-5,08

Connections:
24VIN: F1.1, X1.1, X1.2
+3V3: C1.1, C2.2, C27.1, C28.1, C29.1, IC2.1 (VDD), IC2.5 (VDDA), IC2.17 (VDD), K5.1, R2.2, R7.2, R41.2, R42.2, R43.2, R44.2, R47.2, R49.2, R51.2, R53.2, R55.2, R57.2, R59.2, U1.PAD (OUT), U$1.3 (VDD)
ADC1_DIM1: IC1.2 (PB3), Q1.4 (D), R6.2
ADC1_DIM2: IC3.2 (PB3), Q2.4 (D), R12.2
ADC1_DIM3: IC5.2 (PB3), Q5.4 (D), R25.2
ADC1_DIM4: IC7.2 (PB3), Q4.4 (D), R18.2
ADC2_DIM1: IC1.3 (PB4), R1.1, R3.2
ADC2_DIM2: IC3.3 (PB4), R4.1, R5.2
ADC2_DIM3: IC5.3 (PB4), R22.1, R23.2
ADC2_DIM4: IC7.3 (PB4), R16.1, R17.2
CAN_H: U$1.7 (CANH), X1.8
CAN_L: U$1.6 (CANL), X1.7
CAN_RX: IC2.21 (PA11/CAN_RX/TIM1_CH4/USB_DM), U$1.4 (RXD)
CAN_TX: IC2.22 (PA12/CAN_TX/USB_DP), U$1.1 (TXD)
CTRL1: IC1.6 (MISO/PB1), OK3.4 (COL), R30.1
CTRL2: IC3.6 (MISO/PB1), OK4.4 (COL), R32.1
CTRL3: IC5.6 (MISO/PB1), OK5.4 (COL), R34.1
CTRL4: IC7.6 (MISO/PB1), OK6.4 (COL), R36.1
DI1: R8.2, X3.2
DI2: R48.2, X3.3
DI3: R50.2, X3.4
DI4: R52.2, X3.5
DI5: R54.2, X3.6
DI6: R56.2, X3.7
DI7: R58.2, X3.8
DI8: R60.2, X3.9
DIM1_GND: C9.2, C10.2, D1.A, D20.A, D23.A, D42.A, IC1.4 (GND), OK3.3 (EMIT), R3.1, R6.1, R29.1, T2.2 (S)
DIM1_VDD: D2.C, D21.C, D22.A, Q1.3 (S), R1.2, R11.2
DIM2_GND: C3.2, C4.2, D24.A, D26.A, D29.A, D43.A, IC3.4 (GND), OK4.3 (EMIT), R5.1, R12.1, R31.1, T4.2 (S)
DIM2_VDD: D25.C, D27.C, D28.A, Q2.3 (S), R4.2, R15.2
DIM3_GND: C5.2, C7.2, D36.A, D38.A, D41.A, D44.A, IC5.4 (GND), OK5.3 (EMIT), R23.1, R25.1, R33.1, T8.2 (S)
DIM3_VDD: D37.C, D39.C, D40.A, Q5.3 (S), R22.2, R28.2
DIM4_GND: C8.2, C11.2, D30.A, D32.A, D35.A, D45.A, IC7.4 (GND), OK6.3 (EMIT), R17.1, R18.1, R35.1, T6.2 (S)
DIM4_VDD: D31.C, D33.C, D34.A, Q4.3 (S), R16.2, R21.2
DIMMER1: D20.C, D21.A, R10.2, X2.2
DIMMER2: D26.C, D27.A, R13.2, X2.4
DIMMER3: D38.C, D39.A, R26.2, X2.6
DIMMER4: D32.C, D33.A, R19.2, X2.8
GATE_DIM1: Q1.1 (G), R9.1, T2.3 (D)
GATE_DIM2: Q2.1 (G), R14.1, T4.3 (D)
GATE_DIM3: Q5.1 (G), R27.1, T8.3 (D)
GATE_DIM4: Q4.1 (G), R20.1, T6.3 (D)
GND: C1.2, C2.1, C13.2, C27.2, C28.2, C29.2, D4.A, D5.A, D7.A, D9.A, D11.A, D13.A, D15.A, D17.A, D19.A, IC2.16 (VSS), IC2.32 (VSS), K5.3, OK1.2 (C), OK1.4 (C), OK1.6 (C), OK1.8 (C), OK1.9 (EMIT), OK1.11 (EMIT), OK1.13 (EMIT), OK1.15 (EMIT), OK2.2 (C), OK2.4 (C), OK2.6 (C), OK2.8 (C), OK2.9 (EMIT), OK2.11 (EMIT), OK2.13 (EMIT), OK2.15 (EMIT), R24.1, R45.1, T9.2 (S), T10.2 (S), T11.2 (S), T12.2 (S), U1.1 (ADJ), U$1.2 (VSS), X1.3, X1.4, X1.5, X1.6, X1.9, X1.10, X3.1, X3.10
IN1: IC2.6 (PA0/ADC_IN0), OK1.16 (COL), R7.1
IN2: IC2.7 (PA1/TIM2_CH2/ADC_IN1), OK1.14 (COL), R47.1
IN3: IC2.8 (PA2/USART2_TX/TIM2_CH3/ADC_IN2), OK1.12 (COL), R49.1
IN4: IC2.9 (PA3/USART2_RX/TIM2_CH4/ADC_IN3), OK1.10 (COL), R51.1
IN5: IC2.10 (PA4/SPI1_NSS/TIM14_CH1/ADC_IN4), OK2.16 (COL), R53.1
IN6: IC2.11 (PA5/SPI1_SCK/ADC_IN5), OK2.14 (COL), R55.1
IN7: IC2.12 (PA6/SPI1_MISO/TIM3_CH1/ADC_IN6), OK2.12 (COL), R57.1
IN8: IC2.13 (PA7/SPI1_MOSI/TIM3_CH2/ADC_IN7), OK2.10 (COL), R59.1
unnamed: C8.1, D45.C, IC7.8 (VCC), R36.2, R40.1
unnamed: D29.C, R15.1, T3.3 (G)
unnamed: D28.C, T3.1 (D)
unnamed: D22.C, T1.1 (D)
unnamed: D23.C, R11.1, T1.3 (G)
unnamed: C9.1, D42.C, IC1.8 (VCC), R30.2, R37.1
unnamed: C3.1, D43.C, IC3.8 (VCC), R32.2, R38.1
unnamed: D3.C, R8.1
unnamed: D35.C, R21.1, T5.3 (G)
unnamed: D3.A, D4.C, OK1.1 (A)
unnamed: D34.C, T5.1 (D)
unnamed: C7.1, D44.C, IC5.8 (VCC), R34.2, R39.1
unnamed: D41.C, R28.1, T7.3 (G)
unnamed: D40.C, T7.1 (D)
unnamed: C10.1, R9.2, R37.2, T1.2 (S)
unnamed: OK3.1 (A), R41.1
unnamed: C4.1, R14.2, R38.2, T3.2 (S)
unnamed: OK3.2 (C), T9.3 (D)
unnamed: OK4.1 (A), R42.1
unnamed: C5.1, R27.2, R39.2, T7.2 (S)
unnamed: D6.C, R48.1
unnamed: OK4.2 (C), T10.3 (D)
unnamed: D6.A, D7.C, OK1.3 (A)
unnamed: OK5.1 (A), R43.1
unnamed: C11.1, R20.2, R40.2, T5.2 (S)
unnamed: IC5.1 (RST/PB5), R33.2
unnamed: OK5.2 (C), T11.3 (D)
unnamed: OK6.1 (A), R44.1
unnamed: OK6.2 (C), T12.3 (D)
unnamed: X2.9, X2.10
unnamed: R45.2, U$1.8 (RS)
unnamed: IC1.1 (RST/PB5), R29.2
unnamed: IC3.1 (RST/PB5), R31.2
unnamed: IC7.1 (RST/PB5), R35.2
unnamed: D8.C, R50.1
unnamed: D8.A, D9.C, OK1.5 (A)
unnamed: D10.C, R52.1
unnamed: D10.A, D11.C, OK1.7 (A)
unnamed: D12.C, R54.1
unnamed: D12.A, D13.C, OK2.1 (A)
unnamed: D14.C, R56.1
unnamed: D14.A, D15.C, OK2.3 (A)
unnamed: D16.C, R58.1
unnamed: D16.A, D17.C, OK2.5 (A)
unnamed: D18.C, R60.1
unnamed: D18.A, D19.C, OK2.7 (A)
PHASE1: D1.C, D2.A, R10.1, X2.1
PHASE2: D24.C, D25.A, R13.1, X2.3
PHASE3: D36.C, D37.A, R26.1, X2.5
PHASE4: D30.C, D31.A, R19.1, X2.7
PWM1: IC2.28 (PB5/SPI1_MOSI/TIM3_CH1), T9.1 (G)
PWM2: IC2.27 (PB4/SPI1_MISO/TIM3_CH2), T10.1 (G)
PWM3: IC2.14 (PB0/TIM3_CH3/ADC_IN8), T11.1 (G)
PWM4: IC2.15 (PB1/TIM3_CH4/TIM14_CH1/ADC_IN9), T12.1 (G)
PWM_DIM1: IC1.5 (MOSI/PB0), T2.1 (G)
PWM_DIM2: IC3.5 (MOSI/PB0), T4.1 (G)
PWM_DIM3: IC5.5 (MOSI/PB0), T8.1 (G)
PWM_DIM4: IC7.5 (MOSI/PB0), T6.1 (G)
SWCLK: IC2.24 (PA14/USART2_TX/SWCLK), K5.2
SWDIO: IC2.23 (PA13/SWDIO/USB_NOE), K5.4
UC_BOOT: IC2.31 (BOOT0), R24.2
UC_NRST: IC2.4 (NRST), K5.5, R2.1
VCC: C13.1, D5.C, F1.2, U1.2 (IN)

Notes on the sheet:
Microcontroller
Digital In
CAN
Zener - BZG03C30TR3
Power Supply
Dimmer Out
Author Bernhard Trinnes
ARGE guh
bernhard.trinnes@guh.guru
Licensed under CERN OHL v.1.2

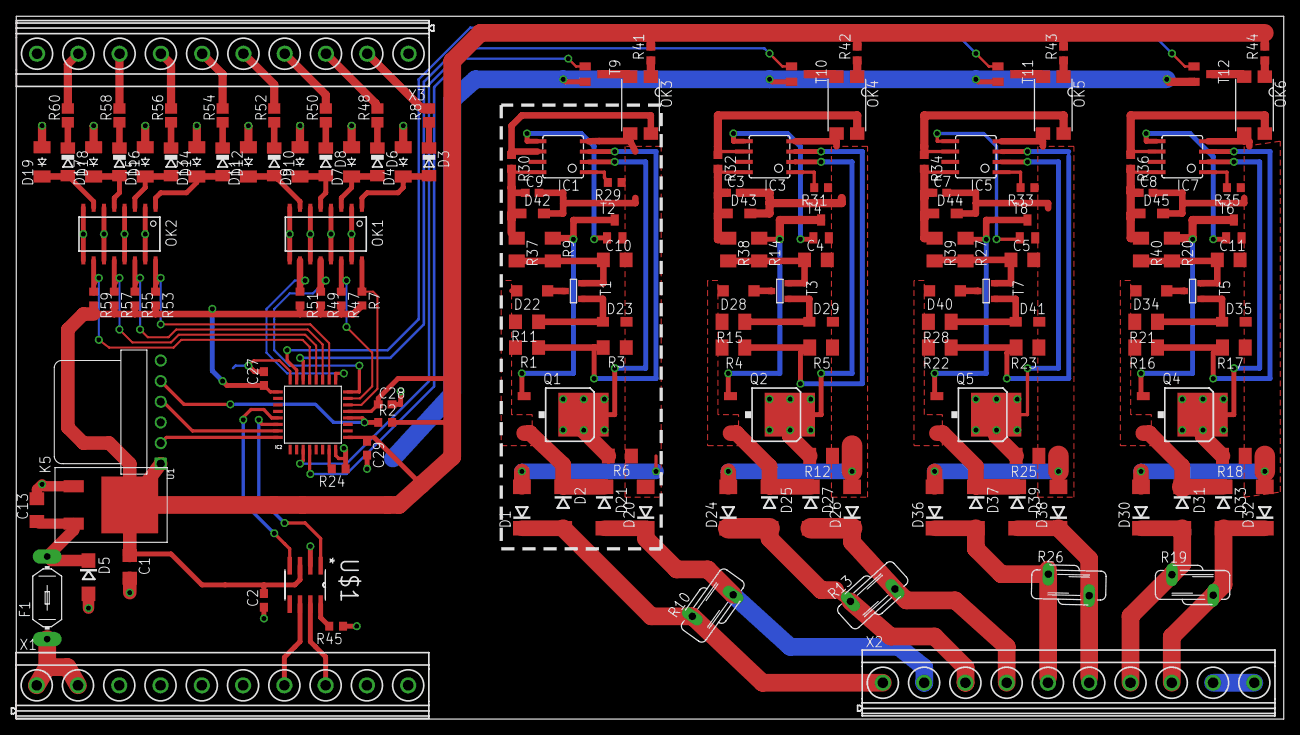
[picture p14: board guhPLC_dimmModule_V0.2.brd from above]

Board: 2 copper layers, 156.0 x 86.5 mm, 152 parts (0 on the bottom side), 114 nets.

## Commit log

2015-08-14 initial project version
    [guhPLC_V0.1.brd, guhPLC_V0.1.sch]
2015-08-16 added pull ups for i2C changed the port for the 32kHz crystal at STM32
    [guhPLC_V0.1.brd, guhPLC_V0.1.sch]
2015-08-18 Added License to README Minor bug fixes
    [guhPLC_V0.1.brd, guhPLC_V0.1.sch]
2015-08-20 Added 1-wire interface
    [guhPLC_V0.1.brd, guhPLC_V0.1.sch]
2015-08-20 Added guhPLC dimmer module initial version
    [guhPLC_dimmModule_V0.1.brd, guhPLC_dimmModule_V0.1.sch]
2015-08-29 Dimmer module now with CAN instead of RS485 - uC changed to STM32F042K6
    [guhPLC_dimmModule_V0.2.brd, guhPLC_dimmModule_V0.2.sch]
2015-08-31 Initial commit 6LowPan Module IEEE802.15.04 - 2.4GHz
    [guhPLC_6LowPANModule.brd, guhPLC_6LowPANModule.sch]
2015-08-31 Changed RS485 to CAN Bus - for better multi master communication
    [guhPLC_V0.2.brd, guhPLC_V0.2.sch]
2015-08-31 Removed old version of the dimmer module
    [guhPLC_dimmModule_V0.1.brd, guhPLC_dimmModule_V0.1.sch]
2015-10-06 New Smart Meter Interface
    [guhPLC_SmartMeterInterface.brd, guhPLC_SmartMeterInterface.sch]

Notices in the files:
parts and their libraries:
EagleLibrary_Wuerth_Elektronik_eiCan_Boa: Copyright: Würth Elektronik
